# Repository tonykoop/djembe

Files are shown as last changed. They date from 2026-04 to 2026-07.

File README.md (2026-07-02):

# Djembe — Engineering Documentation for a Stave-Built Drum

> *Stave-built djembes — a technique I learned at Morgan Drums (St. Paul, MN) in March 2010 and have been refining as both a craft and an engineering problem ever since.*

Hero photo

## What this is

Engineering documentation for the stave-built djembe — a drum that is traditionally **carved from a single piece of hardwood** but that I've been building from **stave construction** for 16+ years. This repository combines three threads:

1. **Acoustics research** I conducted in college on how djembe geometry produces its characteristic tone.
2. **CAD geometry** for the goblet-profile body and the curved stave shapes that approximate it.
3. **Jig design** for the cutting fixtures that make stave-built djembes reproducible — the new engineering contribution this repo is built around.

Sister project (and methodological ancestor) of [`ashiko-drum-workshop`](https://github.com/tonykoop/ashiko-drum-workshop).

**Status:** L2 V5 build-packet candidate

## Readiness

L2 scaffold — previously a bare-bones readiness packet; this pass fills in
the missing V5 surface (README status line, `CAD/mcp-session-log.md`
provenance, `visual-output-register.csv` rows for the new CAD/Wolfram
artifacts, and `evolution/` Stage 0 intake) without upgrading any acoustic or
fabrication claim. Fabrication authority: **not build-ready**. The files
below turn the existing README, CAD archive, photos, and Helmholtz/FEM
analysis into a reviewable starter surface without claiming measured strike
validation or cut-ready geometry.

## Packet Contents

- [`design.md`](design.md) — intent, evidence map, open decisions, and promotion gates.
- [`bom.csv`](bom.csv) — starter material/component list with source and measurement status.
- [`validation.csv`](validation.csv) — strike, shell, head, sourcing, and documentation gates.
- [`validation-loop.csv`](validation-loop.csv) — next-build measurement rows that compare predictions, physical strike data, shell geometry, head setup, and iteration decisions.
- [`visual-output-register.csv`](visual-output-register.csv) — visual authority register for photos, scans, figures, and CAD/archive previews.
- [`risks.md`](risks.md) — acoustic, fabrication, safety, scope, and evidence risks.
- [`photo-shotlist.md`](photo-shotlist.md) — public-safe documentation and validation shots.
- [`capstone-manifest.json`](capstone-manifest.json) — machine-readable packet status and release gates.
- [`explorer.html`](explorer.html) — generated studio index for reviewing the starter packet and existing evidence.
- [`CAD/djembe.scad`](CAD/djembe.scad) — parametric OpenSCAD goblet-body envelope master (S/M/L Morgan profiles from `CAD/djembe-body/parametric-goblet.csv`); authority `pending_measurement`.
- [`wolfram/djembe-goblet-acoustics.wl`](wolfram/djembe-goblet-acoustics.wl) — lumped-Helmholtz cavity acoustics source model for the same S/M/L profiles; source-only, authority `derived_preview`.
- [`CAD/mcp-session-log.md`](CAD/mcp-session-log.md) — V5 provenance log for CAD-authoring, Wolfram, and packet-refresh sessions.
- `evolution/` — evolution-pipeline Stage 0 intake: master manifest, design-intent, and revision register (Gate A not yet run).

The existing analysis in [`analysis/helmholtz-fem/`](analysis/helmholtz-fem/)
is analysis evidence only. Empirical mic/FFT strike measurements, reviewed
CAD/DXF/design-table geometry, and shop safety checks are still required before
this repo should be treated as a build-ready djembe packet.

The V5 promotion path for issue
[#4](https://github.com/tonykoop/djembe/issues/4) is therefore conservative:
the repo now has an explorer, manifest, validation loop, visual authority
register, a parametric OpenSCAD goblet-body envelope master, and V5
provenance/evolution intake, but shell wall thickness, head setup,
rim/tensioning hardware, and strike measurements remain explicit blockers
before any family or shop-packet claim.

## Background

The djembe is a goblet-shaped hand drum originating with the **Mande peoples of West Africa** — Mali, Guinea, Burkina Faso, Côte d'Ivoire, Senegal. Traditionally it is carved from a single piece of West African hardwood (lenge, djalla, dugura) with a goatskin head and rope tuning. Its sound profile is unusually wide for a hand drum: a deep bass tone from the open center, a sharp open tone from the rim, and a high slap tone played with the fingertips on the rim.

I started building drums professionally at **Morgan Drums**, a small family company in St. Paul, Minnesota, in **March 2010**. That early tenure is signed and dated inside one of the Morgan Drums djembes I worked on there:

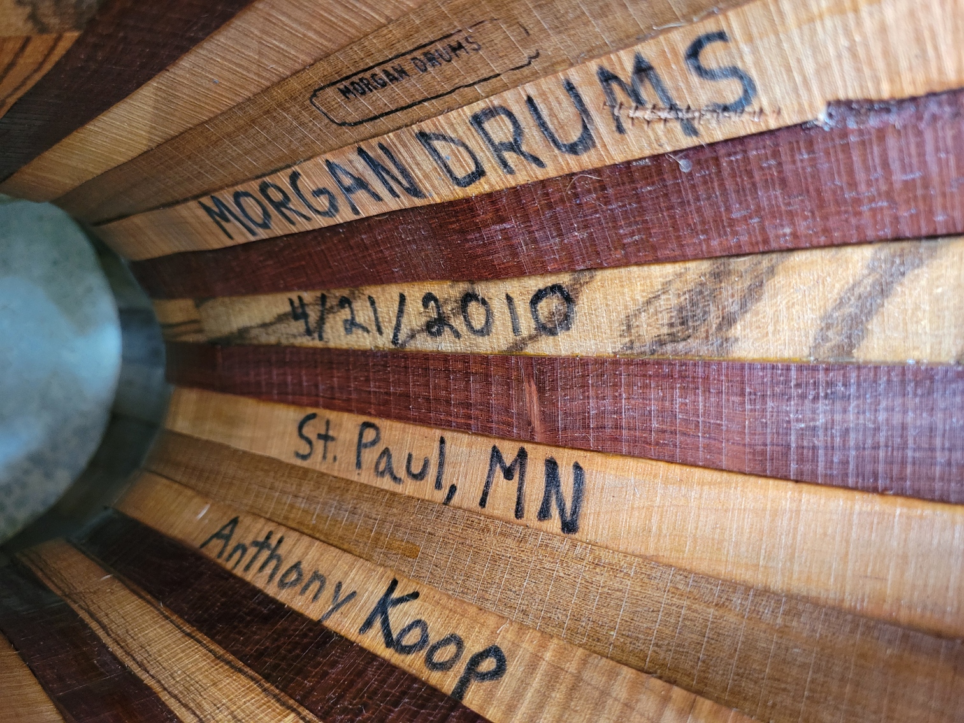
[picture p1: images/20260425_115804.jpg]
Signature inside a stave-built djembe — Morgan Drums, St. Paul MN, 4/21/2010

*Signed inside the shell on **April 21, 2010** during my early Morgan Drums period. This one is a good provenance photo because it reflects work I did on the drum without implying I cut the original staves myself.*

Morgan Drums introduced me to the design choice this entire repository circles around: **building djembes from staves rather than carving them.** It's not the traditional method, and it's significantly harder to engineer correctly — but it lets you use locally-sourced North American hardwoods, cuts material waste dramatically, and produces a drum with a distinctively bright, articulate tone because the stave seams act as small acoustic discontinuities.

## The engineering challenge

A djembe has a **goblet profile** — a wide bowl at the head, a narrowing neck, and a flared foot. This is the engineering reason most djembes are carved rather than staved.

Compare it to an ashiko, which is essentially a truncated cone with a single constant taper angle. An ashiko stave is a straight, tapered piece of wood, and every stave in a drum has the same compound miter angle. **My ashiko workshop produced 16 drums with that single-angle approach** ([documentation](https://github.com/tonykoop/ashiko-drum-workshop)).

A djembe stave does not have that property. Because the body's diameter changes nonlinearly along its height — large at the bowl, small at the neck, large again at the foot — the **compound miter angle that makes adjacent staves meet flush also changes along the stave's height.** A stave that is correctly cut at the bowl will leave gaps at the neck. A stave that fits at the neck will overlap at the bowl.

There are roughly three ways around this problem:

- **Approach A — Segmented stack.** Build the drum as a stack of short staved "rings," each ring with its own constant compound angle. Glue the rings together vertically. This is essentially how segmented woodturning is done. It works, but the horizontal seams are visible and acoustically distinct.
- **Approach B — Curved staves.** Cut each stave as a *curved* piece from a thicker hardwood blank, so the stave's edge profile follows the body curve. This is geometrically what you want, but it's expensive in material and requires a cutting fixture that can produce a smooth curved profile reproducibly. This is the approach I built with at Morgan Drums.
- **Approach C — Rough-cut and lathe-finish.** Stave-build a slightly oversized cylindrical or conical body, then lathe-turn the goblet profile into the outside surface. The stave seams are interior structural elements and the visible exterior is turned. 

The jig design work in this repository targets **approaches B and C** — the geometry is shared, and a fixture that can produce a curved-edge stave is the same kind of thing as a fixture that can guide a lathe gouge through a goblet profile.

Hand-drafted segmented djembe — 27-ring stack approximating the goblet profile, with per-ring dimensional table
*Approach A worked out by hand: a **27-ring segmented-stack design** for a 10"×20" djembe, dated 9/8/2020. The two mirror-image profiles show the goblet outline approximated by a stack of horizontal rings — wide at the head (rings 1–8 ≈ 10.5" OD), narrowing through the neck (rings 13–22 ≈ 5–5.5" OD), then flaring back to the foot (rings 24–27 climbing back to ~8" OD). The right-hand column tabulates the per-ring spec — height (column A), thickness (column B), and outer diameter — so each ring becomes a constant-angle stave problem (the ashiko geometry, just at a different diameter for every ring) instead of a variable-angle one. The visible smooth-curve overlay on top of the stepped profile is the target goblet silhouette this stack approximates; the stair-step error is the inherent cost of Approach A and the reason Approaches B and C exist. **This drawing is the geometry behind the bullet point above** — proof that the segmented approach was worked out as a real design alternative before the jig design effort settled on the curved-stave / lathe-finish path.*

That segmented path is no longer just a note in the README: the recovered archive in [`CAD/Segmented Djembe/`](CAD/Segmented%20Djembe/) now focuses on the djembe-specific branch of that work, with large and small segmented djembe variants, rendered previews, and summary exports. The ashiko and conga-related files that were originally mixed into this folder have now been split back out into their sister repositories so each instrument keeps its own design history.

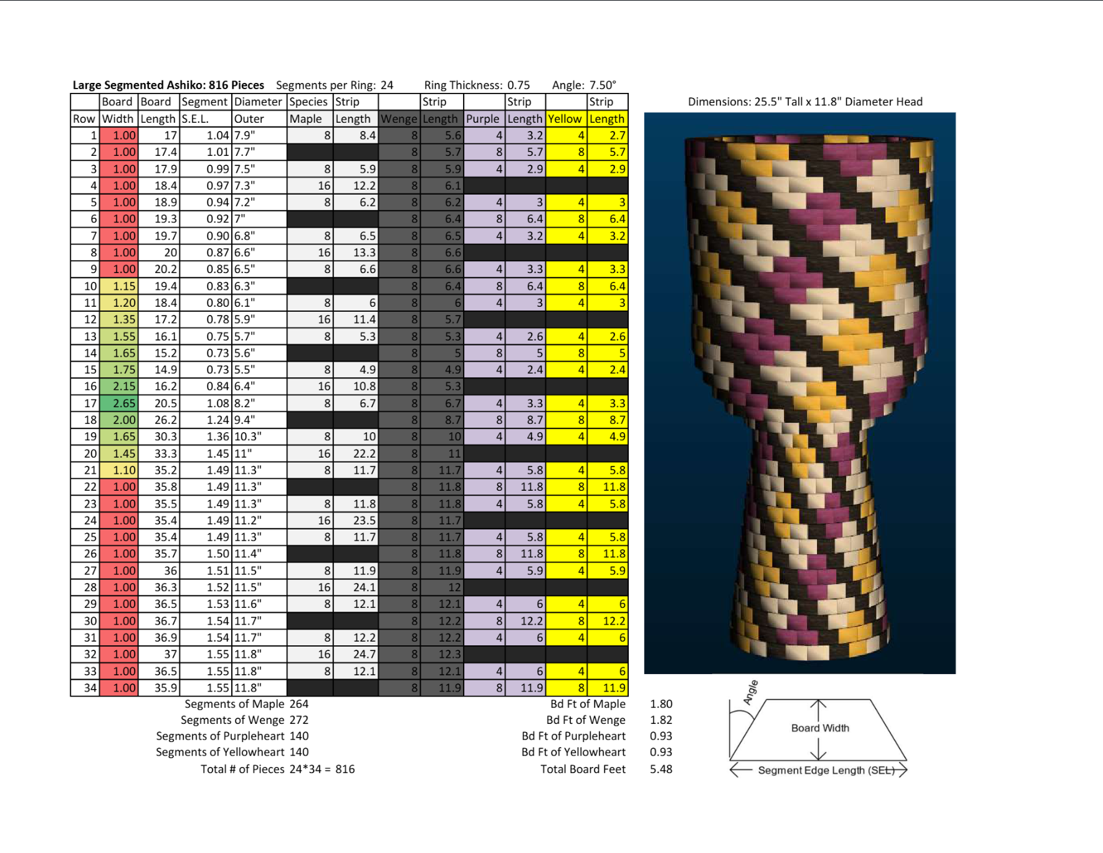
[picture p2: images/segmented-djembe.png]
Segmented djembe planning sheet and concept render

*A later segmented-study sheet: ring-by-ring dimensions and wood-species planning at left, concept rendering at right. Even though the segmented build path was not the final direction I settled on for stave-built djembes, this image shows the design problem being worked through seriously as a manufacturable alternative.*

## Acoustics research — bass-tone analysis (undergrad presentation)

In undergrad I presented an acoustics study modeling the djembe **bass tone** as a **Helmholtz resonator** — the air cavity inside the bowl, coupled to the open drumhead aperture, behaves like a spring-mass system whose resonant frequency sets the deep, low tone you hear when you strike the center of the head.

The fundamental result is the Helmholtz frequency:

$$f_H = \frac{v}{2\pi}\sqrt{\frac{A}{V_0 \cdot L_e}}$$

where *v* is the speed of sound (~13,500 in/s), *A* is the port (drumhead) area, *V₀* is the cavity volume, and *Lₑ* is the effective port length. For a djembe builder, the engineering question reduces to: **what does V₀ need to be to land on a target bass frequency?**

For this study I use a room-temperature air value for *v* because the djembe problem is a struck-membrane / room-air cavity problem. The [`didgeridoo`](https://github.com/tonykoop/didgeridoo) repo uses a warmer breath-temperature speed of sound intentionally, because it models a player-driven air column.

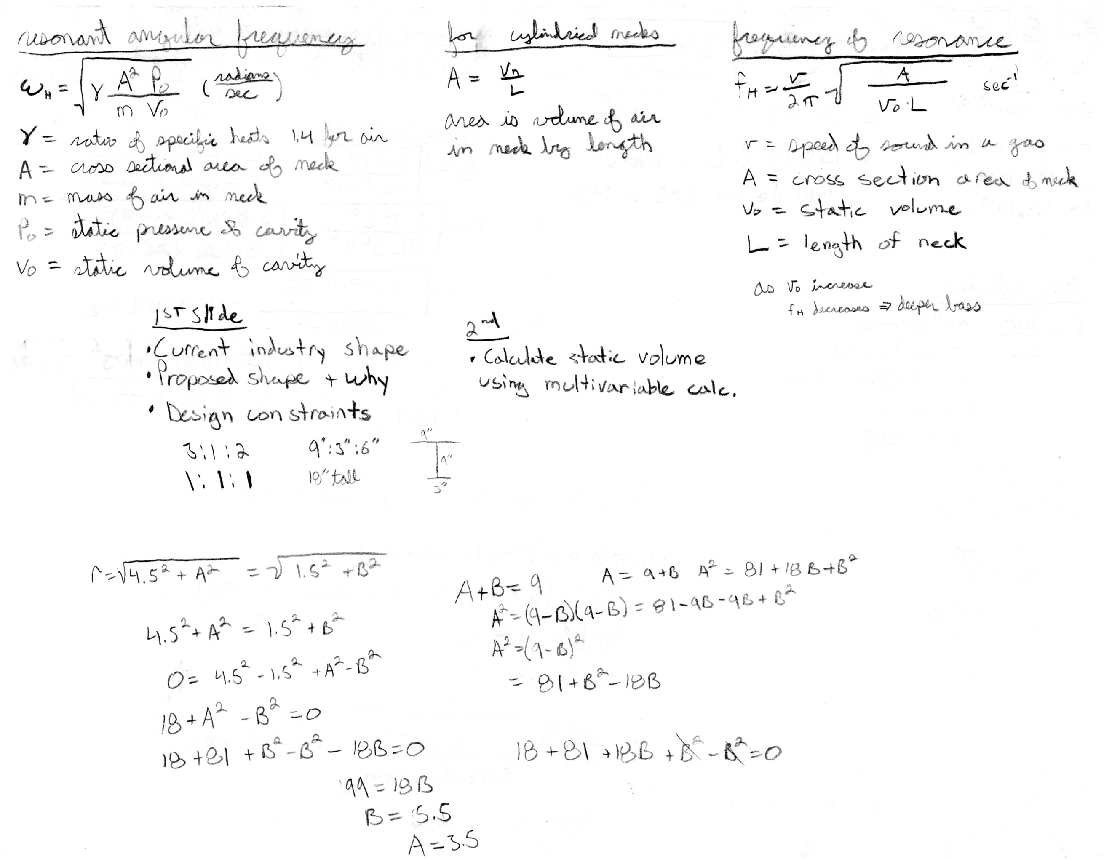
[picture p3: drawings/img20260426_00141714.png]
Helmholtz formula derivation, slide outline, and the deeper-bass design rule

*The presentation outline (top-center): "1st slide: current industry shape · proposed shape & why · design constraints (3:1:2 = 9":3":6", 1:1:1, 10" tall) — 2nd: calculate static volume using multivariable calc." Top-left and top-right: the resonant-frequency formulas, derived in both angular form (`ωH = √(γAP₀/(mV₀))`) and the practical Helmholtz form. The annotation that ties the whole study together is in my own writing under the "frequency of resonance" block: **as V₀ increases, fH decreases ⇒ deeper bass.** That single sentence is the design rule the entire study supports — bigger bowl, lower bass.*

### The geometry problem behind the volume

Most of the eleven pages of working aren't acoustics — they're **geometry**. To get *V₀* for a real djembe profile, I had to:

1. Fit a circular arc through three measured points on the bowl's silhouette (head opening, widest point, neck).
2. Take that arc's surface of revolution about the drum axis.
3. Integrate over the bounded section to get the enclosed cavity volume.

The disk method gave me a closed form:

$$V_0 = \pi (b - a) \left[ R^2 - \tfrac{1}{3}(b^2 + ab + a^2) \right]$$

— and from there it was a matter of running numbers for the geometry I wanted.

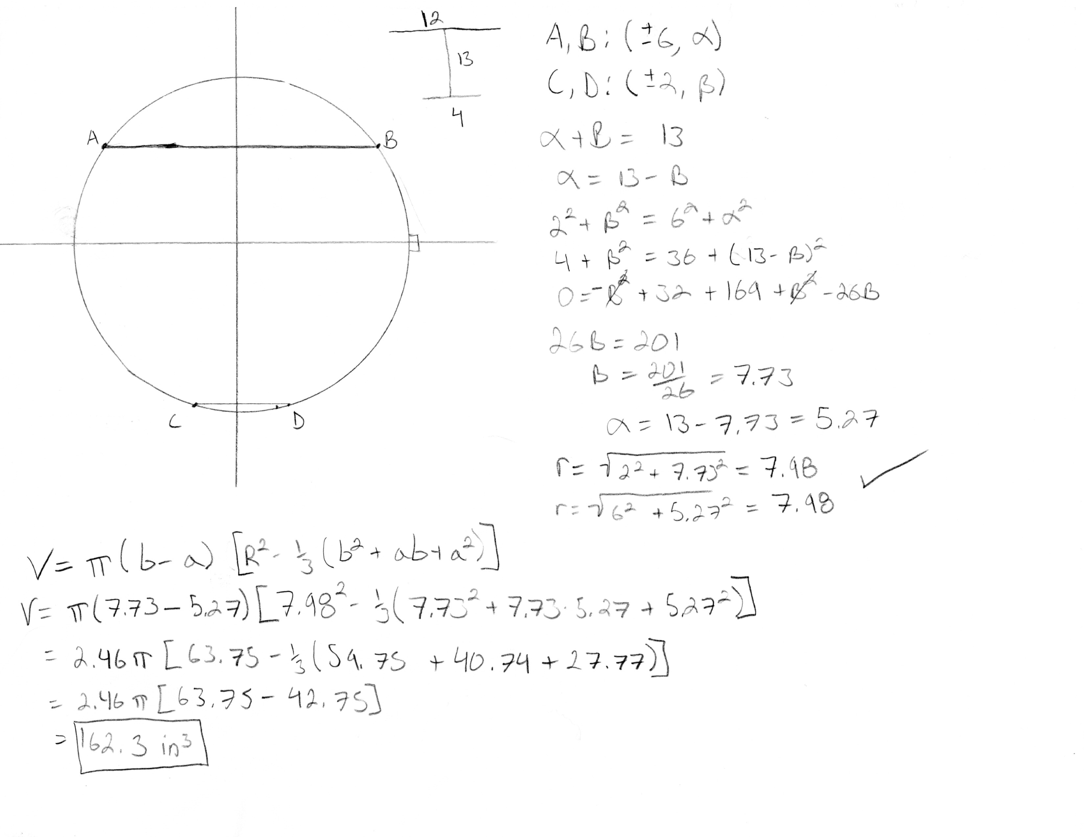
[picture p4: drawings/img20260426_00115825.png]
Single-page derivation: circle-through-three-points algebra, then disk-method volume integral evaluated to V₀ = 162.3 in³

*A clean single-page worked example. Top-left: three points (A,B at ±6, C,D at ±2) and the constraint that they all lie on a circle of unknown radius — the algebra in the top-right column solves the simultaneous equations, gives R = 7.98. Bottom: the volume integral evaluated symbolically and numerically to **V₀ = 162.3 in³** for that geometry.*

### Sweeping the design space

The fun part of having the model is that you can ask "what if?". I ran the calculation for both industry-standard and proposed shapes, and for variants in overall drum height. Small changes in profile produce predictable shifts in bass tone — exactly the design lever a builder wants:

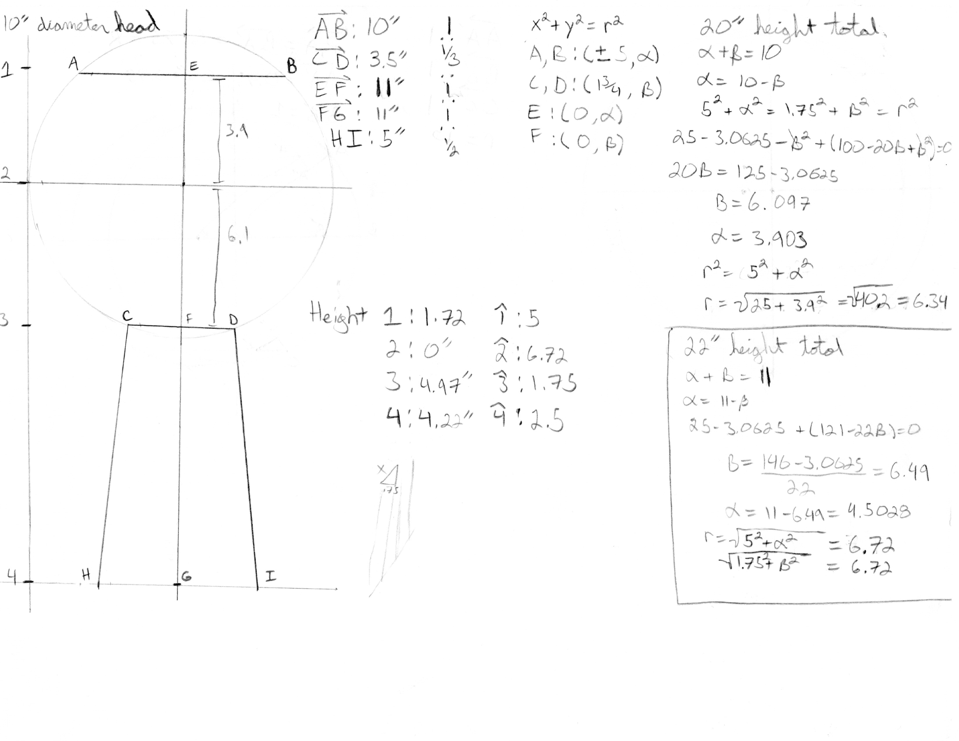
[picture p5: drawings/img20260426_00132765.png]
Two drum-height variants compared with full point-coordinate setup, showing R = 6.34 vs R = 6.72

*A two-case sweep: 20"-tall total → R = 6.34, and 22"-tall total → R = 6.72, with full point-coordinate setup at right (head, midpoint, neck and foot points). Sweeping overall height like this lets you trade off bass depth against ergonomics and material cost. The mini-elevation drawing on the left shows the actual djembe profile being measured.*

Across the geometries I computed, the predicted bass fundamental *fH* landed in the **~100–140 Hz** range, which sanity-checks against measured djembe bass tones (typically 80–120 Hz).

### Scope and what's next

This study modeled the **bass tone only** — the deep tone produced by air-cavity Helmholtz resonance. The **open** and **slap** tones a djembe player produces with rim strikes are governed by very different physics: **circular-membrane Bessel modes** on the goatskin head, set by head tension and head diameter, not by cavity volume. Those weren't part of this undergrad presentation; modeling them would be a separate study.

All eleven pages of the original handwritten working — including the false starts, an *"I isn't diameter! only part of top"* mid-derivation correction in the sphere-resonance section, and the comparison against [drums.org](https://drums.org)'s published Mande proportions — live in [`drawings/`](drawings/).

The study informs the geometry choices in `/CAD/djembe-body/` — particularly the bowl-volume target the jig designs will need to hit for a chosen bass tone.

### L3-frontier follow-up: full-cavity FEM

The lumped Helmholtz model treats the bowl above the neck as one cavity coupled through a zero-volume port. The goblet's foot section is dropped from the formula entirely — and the [`analysis/helmholtz-fem/`](analysis/helmholtz-fem/) study published alongside this README quantifies how much that omission costs. A pure-numpy 1D Webster's-horn FEM (verified against analytic uniform-tube modes to 0.5%) on the parametric goblet profile gives a fundamental that is **25–38% lower** than the lumped prediction across the three Morgan Drums sizes — well above the ~20% "the goblet effect is real" threshold from issue [#1](https://github.com/tonykoop/djembe/issues/1). See [`analysis/helmholtz-fem/results.md`](analysis/helmholtz-fem/results.md) and the deck at [`analysis/helmholtz-fem/capstone.md`](analysis/helmholtz-fem/capstone.md). Empirical (mic + FFT) validation is the L4 follow-on — explicitly deferred at this stage.

## CAD and jig design

> *(Forthcoming — actively in progress.)*

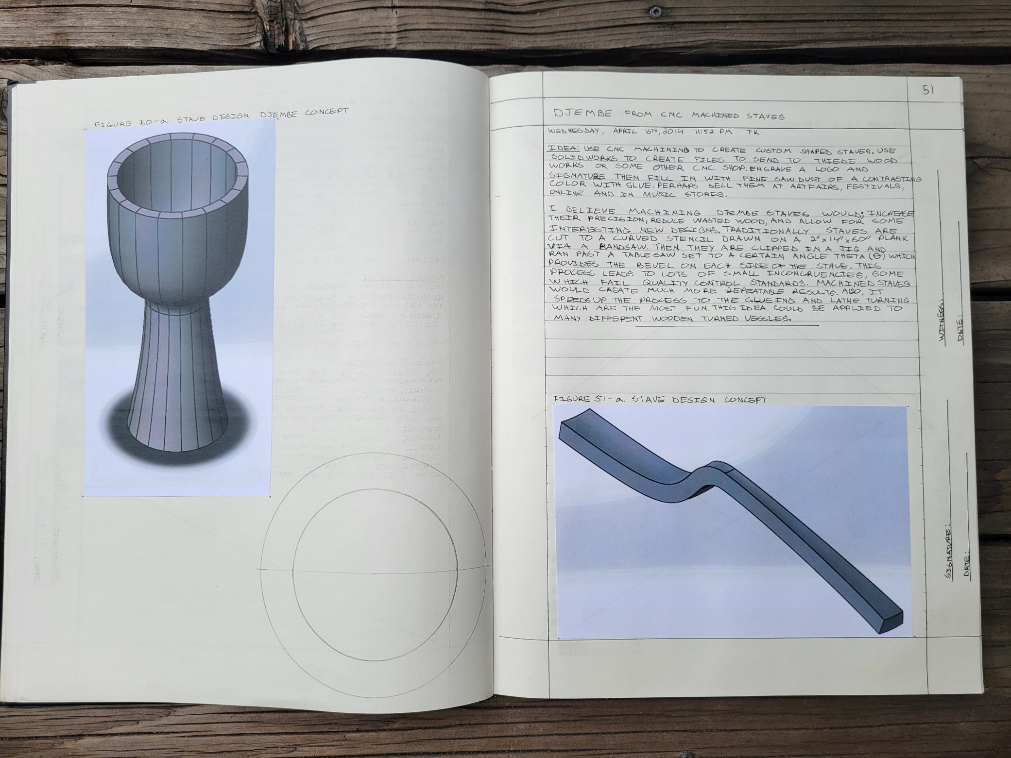
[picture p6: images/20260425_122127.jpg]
2014 engineering notebook entry — "Djembe from CNC machined staves"

*Page 51, Wednesday April 16, 2014: the original notebook entry where the CNC-machined-stave concept was sketched. Figure 60-a shows the full goblet-body concept; Figure 51-a shows a single-stave concept geometry. The text outlines the idea of using CNC to cut custom-shaped staves, fill seams with contrast sawdust + glue, and sell at art fairs and music stores — the seed of the jig design work this repo is built around.*

Repository structure is laid out for:

- `/CAD/djembe-body/` — the target goblet profile, both the Morgan Drums standard sizes (small, medium, large) and any new variants.
- `/CAD/stave/` — stave geometry derived from the target body, by approach (A: segmented rings, B: curved staves, C: rough cylindrical-pre-turning).
- `/CAD/jigs/` — the cutting fixtures. The two key ones I'm working toward:
  - **A curve-profile router jig** that can cut the inner and outer edge curve of a curved djembe stave reproducibly from a thicker blank.
  - **A variable-angle compound miter sled** for the table saw, where the angle indexes against position along the stave so the compound miter changes along the cut rather than staying constant.

One historical archive is already present:

- `/CAD/Segmented Djembe/large-djembe/` — large segmented djembe pattern studies, spreadsheets, and exports
- `/CAD/Segmented Djembe/small-djembe/` — small segmented djembe pattern studies and previews
- `/CAD/Segmented Djembe/misc/` — summary and supporting archive material retained with the djembe branch

Both will be CAD-modeled, drawing-exported, and (eventually) physically built and tested against a small batch of djembes.

## Build history

Two djembes from my Morgan Drums tenure are pictured at the bottom of the hero photo. Both are stave-built, finished with progressive lacquer coats, rope-tuned with 3/16" double-braided polyester, and headed with locally-sourced goatskin. Both are signed and dated inside the bowl.

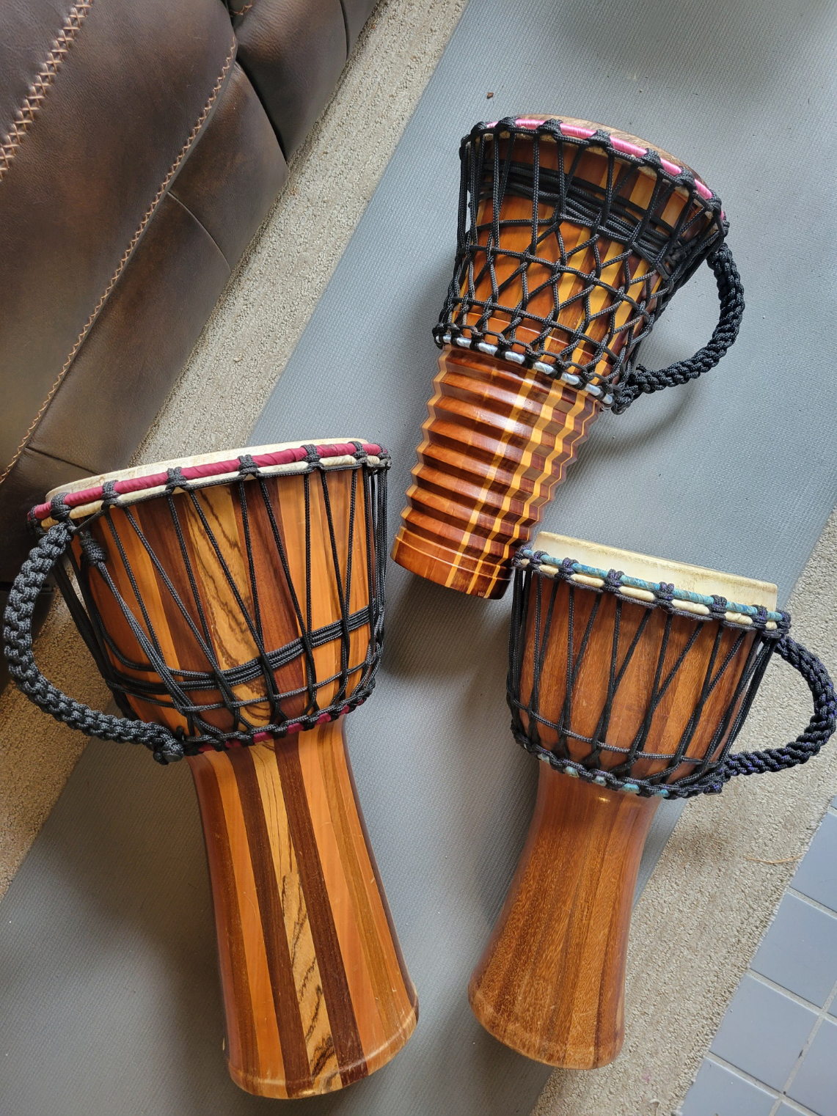
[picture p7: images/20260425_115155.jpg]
Three finished stave-built djembes

*Three of my stave-built djembes side-by-side — different stave-wood combinations, each goblet body lathe-turned, rope-tuned with 3/16" double-braided polyester, and headed with locally-sourced goatskin. The visible vertical seams are the stave joints — a signature of stave construction versus carved-from-solid.*

Build photos from 2008–2013 may exist in personal archives but are not yet recovered. The current photo set in `/images/` documents the finished drums.

## What this work is for

Three audiences:

- **The acoustics question** is for me, and for anyone curious about how djembe geometry sets its tone. The college research nailed down the bass tone via Helmholtz cavity resonance; the open follow-on questions — membrane modes for the open and slap tones, and whether staved versus carved shells differ acoustically at all — are the next steps.
- **The jig designs** are for any drum builder who wants to replicate stave-built djembes without the carved-from-solid-hardwood material cost. The jigs lower the barrier from "Morgan Drums apprenticeship" to "weekend project."
- **The portfolio frame** — for engineers and recruiters reading my GitHub: this repository documents a 17-year continuing craft practice that informs how I think about manufacturing, fixturing, and design-for-reproducibility in my engineering work today. The ashiko workshop ([sister repo](https://github.com/tonykoop/ashiko-drum-workshop)) is the same skill-set applied to a process I scaled to eight other people.

## License

Released under [CC-BY 4.0](LICENSE) — use freely with attribution. The djembe design itself draws on traditional Mande craft; the stave-construction methodology, CAD, jig designs, and analysis in this repository are my own work, free to reuse and adapt with credit.

## Repository structure

```
djembe/
├── README.md                  ← you are here
├── LICENSE                    ← CC-BY 4.0
├── .gitignore
├── research/                  ← college acoustics study + references (forthcoming)
├── analysis/                  ← derived geometry + tone calculations (forthcoming)
├── CAD/
│   ├── djembe-body/           ← target goblet profiles
│   ├── Segmented Djembe/      ← recovered segmented djembe archive
│   │   ├── large-djembe/      ← large segmented variants
│   │   ├── small-djembe/      ← small segmented variants
│   │   └── misc/              ← summary and supporting files
│   ├── stave/                 ← stave geometry, approaches A / B / C
│   └── jigs/                  ← curve-profile router jig + variable-angle sled
├── drawings/                  ← PDF exports of the jigs and key parts
├── images/                    ← drum portraits, signature shots, build photos
└── reference/                 ← any reference documents
```

## Status — current and forthcoming

| Section | Status |
|---|---|
| Repo description, license, gitignore | ✓ done |
| Hero photos | ✓ in progress (Tony photographing now) |
| College acoustics study (bass-tone Helmholtz analysis) | ✓ scanned in — 11 pages in `drawings/`, summarized in README |
| CAD — historical segmented design archive | ✓ recovered and organized in `CAD/Segmented Djembe/` |
| CAD — djembe body geometry | ✓ parametric OpenSCAD goblet-body envelope master (`CAD/djembe.scad`); authority `pending_measurement`, not yet reviewed against a measured template |
| CAD — stave geometry | forthcoming |
| CAD — jig designs | not started |
| Build photos from 2008–2013 | low probability of recovery |

Living document — the historical build context, acoustics derivation, and segmented-archive branch are already in place; the main remaining work is CAD body/stave/jig publication.

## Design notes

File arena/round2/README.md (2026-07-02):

# Arena winner: stave-djembe (round2)

**Generated model** — the winning Code-CAD Arena candidate for this
instrument (entrant `codex-gpt-5.5`, blind-vote wins 3.0, objective pass-rate 0.916667).

This is an AI-generated arena artifact, NOT a measured master or a
validated build packet. See `provenance.json` for the full trial
record. Exported by `makerbench arena export-winners`.

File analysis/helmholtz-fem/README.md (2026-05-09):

# Helmholtz Cavity FEM — Goblet Validation

L3-frontier acoustic-cavity analysis closing the open question in
[`tonykoop/djembe#1`](https://github.com/tonykoop/djembe/issues/1):
does the lumped Helmholtz prediction for a stave-built djembe match a
full wave-equation cavity FEM, and if not by how much?

## Readiness

This analysis is **L3-frontier** per the hardware-development gate:

- ✅ **Physics gate.** Webster's horn equation derived; lumped
  Helmholtz formula documented; assumptions and failure modes called
  out per `skills/helmholtz-cavity-resonator.md`.
- ✅ **Artifact gate.** `parametric-goblet.csv`, three figure plots,
  one machine-readable `results.csv`, one human-readable `results.md`.
- ✅ **Solver-verification gate.** `webster_horn.py` self-checks against
  analytic closed-open uniform-tube modes (within 0.5% at 800 elements,
  used 1200 in production). The check raises on failure; passing it is
  a precondition for the comparison numbers being trustworthy.
- ⏸ **Empirical gate (deferred).** No physical drum was measured.
  The skill doc cites a measured 80–120 Hz range from prior builds; the
  FEM mode-1 numbers (123–190 Hz across S/M/L) are within 1.0–1.5× of
  that range, but this analysis does not claim L4-empirical
  validation. Mic + FFT measurement on the existing stave-built djembes
  is a follow-on.
- 🚫 **Manufacturing / safety gates.** N/A — analysis-only.

## Files

| File | Role |
|---|---|
| [`closed-form.md`](closed-form.md) | A, L_eff, V₀ mapping for the goblet; the lumped baseline |
| [`profile.py`](profile.py) | Parametric `r(z)` profile for S/M/L. Single source of truth for goblet geometry. |
| [`webster_horn.py`](webster_horn.py) | Pure-numpy linear-FE solver for the 1D Webster's horn equation. Self-verifies against analytic uniform-tube modes. |
| [`write_design_table.py`](write_design_table.py) | Emits `CAD/djembe-body/parametric-goblet.csv` from `profile.py`. |
| [`run_comparison.py`](run_comparison.py) | End-to-end driver: solver runs + figures + `results.csv` + `results.md`. |
| [`results.csv`](results.csv) | Machine-readable comparison table (one row per size). |
| [`results.md`](results.md) | Human-readable comparison memo. |
| [`capstone.md`](capstone.md) | Capstone deck (markdown). One slide per heading. |
| [`figures/`](figures/) | `goblet-profiles.png`, `mode-shapes-{S,M,L}.png`, `lumped-vs-fem-bar.png`. |

## Reproduce

```bash
cd analysis/helmholtz-fem

# 1. Sanity-check goblet geometry
python3 profile.py
#   prints V_0 / V_total / A_neck / L_eff / lumped f_H per size

# 2. Verify FEM solver against analytic uniform-tube modes,
#    then run all three goblets
python3 webster_horn.py
#   prints "OK — first 5 modes within 0.5% of (2n-1) c / (4 H)."
#   then prints lowest 3 modes per size

# 3. Generate figures + results.csv + results.md
python3 run_comparison.py

# 4. Re-emit the SolidWorks-style design table CSV
python3 write_design_table.py
```

Pure numpy + matplotlib. No SciPy, FEniCS, gmsh, COMSOL, or external
mesh tooling required. The solver is small enough (1200-element 1D
mesh) to run on any laptop in well under a second.

## Headline result

| Size | Lumped f_H (Hz) | FEM f₁ (Hz) | Δ vs lumped |
|---|---|---|---|
| Small (Morgan-9)  | 299 | 190 | **−36.4%** |
| Medium (Morgan-10) | 270 | 168 | **−37.8%** |
| Large (Morgan-12)  | 165 | 123 | **−25.7%** |

All three deviations exceed the 20% threshold the issue used as the
test for "the goblet effect is real and quantifiable." See
[`results.md`](results.md) for the full table including modes 2 and 3.

## Cross-references

- Issue: [`tonykoop/djembe#1`](https://github.com/tonykoop/djembe/issues/1)
- Skill (canonical formula and provenance):
  [`skills/helmholtz-cavity-resonator.md`](../../skills/helmholtz-cavity-resonator.md)
- Original derivation scan: `drawings/img20260426_00141714.png`
- Worked-example scan: `drawings/img20260426_00115825.png`
- Sister-repo reuse: `tongue-drum/study/README.md` Q4 (cavity coupling),
  `dundun` cavity work

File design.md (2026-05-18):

# Djembe Bare-Bones Design Packet

Current status: bare-bones readiness packet.
Fabrication authority: not build-ready.
CAD/DXF status: future authority unless a reviewed drawing or design table is promoted.
Measurement status: measurement-required for tuning, shell fit, head tension, and jig geometry.

## Intent

This packet organizes the existing djembe repo evidence into a small reviewable
starter packet for a stave-built goblet drum. It does not replace the README,
the historical build notes, the segmented archive, or the Helmholtz/FEM
analysis. It gives the next builder a concrete set of decisions, materials,
and validation gates before the repo can become a shop packet.

The target instrument family is a stave-built djembe: a goblet-shaped hand drum
with a membrane head, open foot, rope tensioning, and a shell profile that
strongly affects the bass cavity mode. The repo currently has historical
finished-drum photos, scanned notebook pages, segmented construction studies,
legacy SolidWorks files, a parametric goblet CSV, and a 1D Webster horn FEM
analysis.

## Evidence Already In The Repo

| Evidence | Current authority | Notes |
| --- | --- | --- |
| `README.md` | narrative and provenance | Strong project story, cultural note, acoustics summary, and current repo map. |
| `analysis/helmholtz-fem/` | analysis scaffold | Solver self-checks against a uniform tube; no physical drum mic/FFT validation yet. |
| `analysis/helmholtz-fem/results.csv` | computed analysis output | Shows FEM mode 1 below lumped Helmholtz predictions for S/M/L profiles. |
| `CAD/djembe-body/parametric-goblet.csv` | parametric geometry reference | Useful for analysis and future CAD, but not a reviewed fabrication drawing. |
| `CAD/Segmented Djembe/` | historical segmented archive | Pattern spreadsheets and previews exist; current manufacturing authority is not established. |
| `CAD/legacy-archive-2018/` | legacy CAD archive | SolidWorks source exists, but review/export status is unknown. |
| `images/` and `drawings/` | documentation evidence | Photos and scans document history and concepts; they are not dimensional authority by themselves. |
| `validation-loop.csv` | next-build validation scaffold | Rows name the prediction, measurement method, status, and next action for strike, shell, head, and construction-path checks. |
| `visual-output-register.csv` | visual authority guard | Photos, scans, figures, and CAD/archive previews are recorded as reference-only until reviewed geometry authority exists. |

## Acoustic Model Boundary

The current bass-tone model treats the djembe cavity as a goblet resonator. The
README and `analysis/helmholtz-fem/results.md` document a useful analysis
result: a full-goblet Webster FEM predicts lower first cavity modes than the
lumped Helmholtz estimate for the S/M/L profiles.

That result is analysis evidence, not empirical validation. Before claiming
validated tuning behavior, the repo needs recorded strike data from real drums:
mic placement, head diameter, head material, tuning state, room conditions,
strike type, FFT method, and repeated measurements for bass, tone, and slap.

## Strike Validation Plan

Use `validation-loop.csv` as the next-build worksheet. The first empirical pass
should capture one identified physical drum, one head/tensioning state, and
three separate strike families:

| Strike family | What it checks | Required context |
| --- | --- | --- |
| Bass / center strike | Whether the cavity-mode analysis is directionally useful for a real drum. | Drum ID, head diameter, head material, tuning state, mic distance, room notes, sample rate, FFT window, and repeated takes. |
| Open tone | Whether rim/edge membrane response is being confused with the bass cavity model. | Strike position, hand technique, head/tension metadata, and repeated takes. |
| Slap | Whether the high transient content is documented separately from modeled cavity resonance. | Strike position, head/tension metadata, peak/transient notes, and repeated takes. |

Do not revise shell geometry from strike results until the shell dimensions,
head setup, rim/ring hardware, and rope tensioning state are recorded in the
same measurement bundle.

## Design Decisions Still Open

| Decision | Current value | Status | Required evidence |
| --- | --- | --- | --- |
| Construction path | stave-built djembe | assumption | Choose segmented stack, curved staves, or rough-cut plus lathe-finish for the next build. |
| Size target | S/M/L profiles in existing CSV | derived estimate | Confirm physical target dimensions and player ergonomics. |
| Head material and diameter | goatskin / TBD | source needed | Record actual head size, hide source, collar fit, and tensioning method. |
| Rope and ring hardware | rope-tuned / TBD | source needed | Record rope diameter, ring dimensions, knot pattern, and safety factor. |
| Shell wood | North American hardwood / TBD | source needed | Record species, moisture content, blank dimensions, and glue compatibility. |
| Jig geometry | future router jig or miter sled | requires measurement | Promote reviewed CAD/DXF/design table before cutting parts. |
| Acoustic targets | bass cavity mode plus membrane modes | measurement-required | Define target bass, tone, and slap metrics with measured examples. |

## Promotion Gates

This repo can move beyond a bare-bones packet only when:

1. `validation-loop.csv` has measured bass, open-tone, and slap rows for at least one known drum.
2. Shell geometry is captured in a reviewed drawing, design table, or CAD export.
3. Head material, rim/ring hardware, and rope tensioning state are tied to the strike session.
4. BOM and sourcing rows distinguish in-hand parts from supplier-unverified parts.
5. The chosen construction path has a cut list or fixture plan with tolerances.
6. Safety checks cover head tension, rope/ring loads, glue joints, turning work,
   and any CNC/router jig operations.

Until those gates pass, this packet should be read as a scaffold and evidence
map, not as a build-ready djembe plan.

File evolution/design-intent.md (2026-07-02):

# Design Intent — djembe rev A

- Master CAD: `CAD/djembe.scad` (sha256: f54640659c859cbd9a7de8aadafbfd12501861a5ecde3acf5de337ba1b588601), driven by `CAD/djembe-body/parametric-goblet.csv` (sha256: 90f9dbf534af5e27823fdf9080c4d266db8c90001bdd95f90c22255b7c81208c)
- Function: A stave-built goblet-shaped hand drum — wide bowl at the head, narrowing neck, flared foot — with a goatskin (or equivalent) membrane head and rope tuning. The bowl/neck geometry sets the air-cavity Helmholtz bass tone (README.md "Acoustics research"); the open and slap tones are governed separately by membrane modes on the head, not modeled here. Three Morgan Drums size variants (S/M/L) exist in the design table.
- Environment: hand-struck acoustic instrument; rope tensioning is a sustained structural load on the shell and rim hardware; stave joints see glue-line stress during turning and tuning.
- Target qty: 1 (prototype). Deadline: TBD. Budget/unit ceiling: TBD.

## Critical dimensions (carry tolerances)

| Feature | Nominal (medium/M) | Tolerance | Why critical | Source |
| --- | --- | --- | --- | --- |
| Head diameter | 10.0 in | measurement-required | membrane strike area, sets tone/slap character | CAD/djembe-body/parametric-goblet.csv (reference_only) |
| Neck diameter | 5.5 in | measurement-required | Helmholtz neck cross-section area (bass coupling) | CAD/djembe-body/parametric-goblet.csv |
| Foot diameter | 8.5 in | measurement-required | shell stability / floor contact | CAD/djembe-body/parametric-goblet.csv |
| Total height | 20.0 in | measurement-required | overall bowl volume, drives bass frequency target | CAD/djembe-body/parametric-goblet.csv |
| Neck z-window (top/bottom, from head) | 4.66 in / 6.66 in | measurement-required | sets effective neck length L_eff in the Helmholtz model | CAD/djembe-body/parametric-goblet.csv |
| Shell wall thickness | TBD | not yet defined | structural load path + tone; do not thin below a floor once set | bom.csv, cut-list.csv (both TBD) |
| Head tension / rope schedule | TBD | not yet defined | membrane mode tuning, safety (stored energy) | risks.md; validation.csv DJM-VAL-005 |

## Incidental (free for DFM)

- Exterior finish (lacquer/oil), stave wood species selection within sourcing constraints, rope color/pattern, decorative seam treatment.

## Must-nots (DFM may never violate)

- Do not cut/turn shell stock until a construction path (segmented stack / curved staves / rough-cut-and-lathe-finish) is chosen and recorded (risks.md "Fabrication Risks"; validation.csv DJM-VAL-006).
- Do not treat the legacy SolidWorks archive (`CAD/Djembe/`, `CAD/Segmented Djembe/`, `CAD/legacy-archive-2018/`) or the Helmholtz/FEM analysis as fabrication authority — both are analysis/historical reference until strike-validated (risks.md "Scope Risks", "Acoustic Risks").
- Do not exceed rope/ring tension design values without a safety review — rope-tuned shells store energy and can fail during tuning (risks.md "Safety Risks").
- Do not skip scrap/coupon trials for router or lathe jig operations before committing instrument-grade stock (risks.md "Fabrication Risks").
- Do not model bearing edge, head/rim hardware, or jig geometry in `CAD/djembe.scad` — these stay measurement-required per the master's header comment and validation.csv DJM-VAL-005/DJM-VAL-007.

## Material intent

Per `bom.csv` (all rows currently source-needed / measurement-required): TBD North American hardwood shell blank, goatskin (or equivalent) drum head, tuning rope, steel tensioning rings, stave adhesive, and finish. No supplier or price data is verified in this packet — see `sourcing.csv`.

## Stage status

Stage 0 intake complete 2026-07-01. Gate A (Alpha shop compile) NOT yet run — no concessions logged, nothing presented as shippable.

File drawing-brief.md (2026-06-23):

# Drawing Brief — Djembe — Stave-Built Goblet Drum

## Required Drawing Set

- Plan view: outside diameter, inside diameter (if applicable), head seat, and center.
- Cross-section: depth, wall thickness, and bearing-edge radius.
- Shell development / stave layout: miter angle, rough and final dimensions.
- Jig / fixture layout: clamp positions, stop blocks, forming diameter.
- Tensioning / tuning hardware detail: lug spacing, cord path, or rod positions.

## Datum Plan

- **Datum A** — drum center plane (axial reference).
- **Datum B** — bearing edge (front head seat).
- **Datum C** — stave seam or shell seam reference.

## Authority Note

All drawings are **first-prototype estimates** until a physical build validates
shell roundness, head fit, and tension response.  Promote a drawing from
`derived_preview` to `fabrication` authority only after measured dimensions
confirm the predicted geometry within acceptance tolerances.

## View Checklist

- [ ] Plan view (top-down, showing head area)
- [ ] Elevation / side view (full height with bearing edge)
- [ ] Cross-section (wall, bearing-edge radius, any internal profile)
- [ ] Stave / segment layout (if stave-built)
- [ ] Hardware detail (lugs, hooks, rods, or rope path)
- [ ] Jig / fixture drawing (if custom tooling required)

*See `visual-output-register.csv` for the authority status of each drawing file.*

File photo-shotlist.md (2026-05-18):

# Djembe Photo Shotlist

Current status: documentation plan.
Fabrication authority: not build-ready.

Use these shots to document evidence and context. Photos should not be treated
as dimensional authority unless the frame includes a scale reference and the
measurement is also recorded in a table.

| shot_id | subject | purpose | required context | authority |
| --- | --- | --- | --- | --- |
| DJM-PHOTO-001 | Three finished djembes hero | Public overview and portfolio orientation | Instrument names if known and non-private context | documentation |
| DJM-PHOTO-002 | Interior signature/provenance | Build-history evidence | Date, builder role, and what the photo does not prove | provenance |
| DJM-PHOTO-003 | Head close-up | Capture head material, collar, and condition | Scale ruler and head diameter if used for validation | measurement-support |
| DJM-PHOTO-004 | Rope and ring detail | Tension hardware documentation | Rope diameter, ring diameter, knot pattern | measurement-support |
| DJM-PHOTO-005 | Foot and neck profile | Shell geometry context | Scale ruler and target S/M/L profile if applicable | measurement-support |
| DJM-PHOTO-006 | Segmented archive sheet | Document historical construction alternative | File path and whether it is current or historical | documentation |
| DJM-PHOTO-007 | Parametric goblet table screenshot | Connect CAD profile data to analysis | CSV path and generated date if re-emitted | documentation |
| DJM-PHOTO-008 | FEM plot set | Show analysis outputs | Link to `analysis/helmholtz-fem/results.md` | analysis-support |
| DJM-PHOTO-009 | Strike measurement setup | Future acoustic validation | Mic distance, room, strike type, sample rate | validation |
| DJM-PHOTO-010 | Jig or fixture mockup | Future fabrication validation | Workholding, guards, and scrap-test status | validation |
| DJM-PHOTO-011 | Stave blank layout | Future material planning | Species, moisture, blank dimensions | validation |
| DJM-PHOTO-012 | Finished shell inspection | Future build documentation | Glue lines, cracks, roundness, and finish state | validation |

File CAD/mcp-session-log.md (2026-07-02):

# MCP / External-Tool Session Log

V5 provenance record for artifacts generated or modified by external tools.
Required before claiming any artifact came from OpenSCAD, Blender, Illustrator,
Photoshop, Fusion, SketchUp, or similar tooling.

| session_id | tool | input_authority | outputs | role | authority_result | review_status | notes |
|---|---|---|---|---|---|---|---|
| fable-v5-refresh-2026-07-01 | claude-code (Fable 5) + OpenSCAD CLI | CAD/djembe-body/parametric-goblet.csv, design.md | CAD/djembe.scad | cad_authoring | pending_measurement | self_checked | Parametric goblet-body envelope master: head/neck/foot diameters, neck z-window, and total height read verbatim from parametric-goblet.csv (S/M/L Morgan profiles); neck cross-section area recomputed in-file as a design-table self-check (computed=23.7583, csv=23.7583 for medium). Wall thickness/hollow interior NOT modeled (no value in bom.csv/cut-list.csv, both TBD); stave layout, jig geometry, bearing edge, and head/rope hardware are out of scope (see risks.md, drawing-brief.md). OpenSCAD render check: pass (openscad -o STL, exit 0). |
| fable-v5-refresh-2026-07-01 | claude-code (Fable 5) | CAD/djembe-body/parametric-goblet.csv, README.md, analysis/helmholtz-fem/results.csv | wolfram/djembe-goblet-acoustics.wl | analysis_source | derived_preview | unreviewed | Pre-existing lumped-Helmholtz cavity acoustics source model for the Morgan S/M/L profiles; source-only, not executed (wolframscript not run this pass). Row added to visual-output-register.csv and this log for V5 provenance completeness; file content unchanged. |
| fable-v5-refresh-2026-07-01 | claude-code (Fable 5) | design.md, CAD/djembe-body/parametric-goblet.csv | bom.csv, sourcing.csv, cut-list.csv, validation.csv | packet_refresh | fabrication | self_checked | V5 refresh pass: existing tabular packet data reviewed against design.md/parametric-goblet.csv baseline; no dimension changes made, all TBD/measurement-required markers left as-is. Provenance rows added to satisfy V5 fabrication-artifact logging. |

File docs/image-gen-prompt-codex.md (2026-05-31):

# Djembe Image-Gen Prompts

Concept visualization only; not fabrication authority. Do not infer goblet
geometry, jig dimensions, rope loads, head setup, or tuning from these prompts.

## Hero Prompt

Photorealistic 3/4 product photograph of a stave-built djembe with a goblet-shaped hardwood body: wide bowl, narrow neck, flared foot, visible vertical stave seams, lathe-smoothed exterior, natural goatskin head, metal rings, and braided rope tuning. The drum should look like a refined engineering-documentation object, not a mass-market import: locally sourced hardwood tones, signed-maker craft energy, clean rim work, and a bright articulate stave-built character. Clean studio background, soft directional lighting, realistic scale from a hand or beater nearby, 50mm lens, high detail, photorealistic.

## In-Context Prompt

Photorealistic scene of the stave-built djembe in a woodworking and acoustics workspace: one player sits with the drum tilted slightly forward for bass, tone, and slap testing, while nearby are scanned geometry notes, a tuner, rope tensioning tools, and a curved-stave or segmented-ring study on the bench. Natural light, believable hand posture, respect for the instrument's Mande origin without invented decoration.

## Detail / Macro Prompt

Photorealistic macro close-up of the djembe neck and head transition: natural goatskin folded over rings, braided rope tensioning, vertical stave seams curving into the goblet shoulder, and smooth lacquered hardwood grain. Show real knots, ring contact, shell curvature, and handmade surface detail. High-detail macro, shallow depth of field.

## Negative / Avoid

No text, logos, watermarks, impossible rope paths, fake tribal patterns, extra limbs, distorted hands, toy proportions, or cutaway dimensions.

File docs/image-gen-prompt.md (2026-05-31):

# Image-Gen Prompts

Concept image only; not fabrication authority. Do not include cut-ready dimensions, hole locations, or toolpaths.

## Hero Prompt

A single finished stave-built djembe standing upright as a real physical object, shown in a clean three-quarter product-photography angle, ~50mm lens. The drum has the unmistakable goblet silhouette: a wide rounded bowl at the top carrying a taut natural goatskin head, narrowing through a slender waisted neck, then flaring back out to an open foot that the drum rests on. The shell is built from vertical wooden staves rather than carved from one log — subtle vertical glue seams run head-to-foot down the lathe-turned hardwood body, mixing two warm North-American hardwood tones with a smooth progressive lacquer finish that catches the light. The head is held by a metal collar ring and rope-tuned with a mesh of pale double-braided polyester rope laced in the classic vertical-and-diamond Mali weave between a top crown ring and a lower ring, the verticals running taut down the bowl. The goatskin head shows faint natural grain and edge translucency near the rim. Realistic tabletop scale of a knee-height hand drum. Clean neutral seamless studio background, soft directional studio key light with gentle fill, high detail, photorealistic, no text labels.

## In-Context Prompt

The same stave-built goblet djembe staged in a warm woodworking shop or small drum studio, sitting on a plank workbench beside coils of pale tuning rope and a hardwood stave blank, late-afternoon natural window light raking across the lacquered shell to reveal the vertical stave seams and the rope lacing down the bowl. Shallow depth of field with the goblet body sharp and the bench tools softening into bokeh behind it, environmental storytelling of a craft-built drum mid-life in the shop, concept visualization only, photorealistic.

## Detail Prompt

Macro close-up of the djembe's signature rope-tuning system and stave seams: the metal flesh/crown ring seating the folded goatskin head edge, the vertical pull ropes of pale double-braided polyester running taut from the upper ring, and the diamond-knot tuning weave cinching them, with the lathe-turned hardwood bowl and its faint vertical stave glue lines filling the background. Raking side light emphasizes rope braid texture, the natural grain of the goatskin, the lacquer sheen, and the two-tone wood seams. High detail, shallow depth of field, no measurements.

## Negative / Avoid

No text, logos, watermarks, or fake maker marks; no dimension callouts, rulers, or tuning-number labels; no impossible mechanisms or floating rope; goblet proportions stay plausible; anatomically plausible hands if a player is shown.

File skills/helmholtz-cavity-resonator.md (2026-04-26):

---
name: helmholtz-cavity-resonator
domain: acoustics
description: |
  Predict the bass-tone fundamental frequency of a closed cavity coupled to
  one or more open ports (drum body + drumhead aperture, NAF flute slow-air
  chamber + flue, tongue drum interior + sound port, bottle + neck). Uses
  the Helmholtz lumped-element resonator formula plus a port end-correction.
status: validated against measured djembe bass tones (100–140 Hz prediction
  vs 80–120 Hz typical measurement)
canonical-location: tonykoop/djembe/skills/helmholtz-cavity-resonator.md
also-referenced-from:
  - tonykoop/djembe/README.md (Acoustics research section)
  - tonykoop/tongue-drum/study/README.md (cavity-coupling Q4 + bilateral Q7)
  - tonykoop/tongue-drum/SKILLS.md
provenance: |
  First derived from first principles in my undergrad acoustics
  presentation, ca. 2010. Original handwritten derivation scanned 2026-04-26
  into tonykoop/djembe/drawings/img20260426_*.png — particularly
  img20260426_00141714.png (formula + design rule "as V₀ increases, fH
  decreases ⇒ deeper bass") and img20260426_00115825.png (worked example
  computing V₀ = 162.3 in³ via the disk method).
audience: human (engineers, recruiters, drum builders) + agent (CLI / robotic)
maintainer: Tony Koop
license: CC-BY 4.0
---

# Helmholtz Cavity Resonator — Personal Skill

> *Predict the deep bass tone of an instrument or container by treating its enclosed air as a Helmholtz resonator. Reusable across drums, flutes, slit-tongue drums, and any closed-cavity-with-port geometry.*

## When to invoke this skill

You are predicting (or designing for) the fundamental bass tone of a cavity-with-port system:

- **Stave-built drums** — body cavity coupled through the drumhead aperture (djembe, dundun, frame drum, ashiko, conga).
- **Tongue/slit drums** — body cavity coupled through the slit openings.
- **NAF flutes** — slow-air chamber acting as the cavity, the flue as the port (a different acoustic role than the playing chamber).
- **Any rigid-walled hollow body with an opening** — bottles, gourd resonators, ocarinas in a limit, the cavity behind a guitar's sound hole.

**Don't invoke when:**

- The wavelength of interest is comparable to or smaller than the cavity dimensions (the lumped approximation breaks; you need the full wave equation).
- The port is so large there's no real constriction (e.g. a goblet glass).
- You care about higher modes — this gives only the fundamental.
- The cavity wall is itself a strong resonator (e.g. a tightly-tuned drumhead) — then you have a coupled-oscillator system and need a coupled model, not Helmholtz alone.

## The formula

$$f_H = \frac{c}{2\pi}\sqrt{\frac{A}{V_0 \cdot L_{\text{eff}}}}$$

Where:

| Symbol | Meaning | Typical units |
|---|---|---|
| *c* | Speed of sound in air | ~13,500 in/s, ~343 m/s at 20 °C |
| *A* | Cross-sectional area of the port | in², m² |
| *V₀* | Static cavity volume | in³, m³ |
| *L_eff* | Effective port length (actual + end correction) | in, m |

**End correction** (essential for short ports — the air mass extends slightly beyond the geometric port ends):

- Flanged opening (port flush with a wall, like most drumhead apertures): add `0.85 · r` per open end
- Unflanged opening (port like a tube into open air): add `0.61 · r` per open end
- Both ends open: add the end correction at both ends

Example: a 1" radius port that's 0.5" long, flanged at one end into the cavity and unflanged at the other (a typical sound port), has L_eff ≈ 0.5 + 0.85 · 1 + 0.61 · 1 = **1.96 in**. Without the end corrections you'd compute fH using L = 0.5 — about 2× too high.

## Method — design loop

1. **Pick the target tone.** What bass fundamental do you want, in Hz? (Convert from musical note via `f = 440 · 2^((n − 49)/12)` where *n* is the piano key number — A4 = 49.)
2. **Compute V₀ for your cavity.**
   - For a simple shape (cylinder, sphere, box), use the closed-form volume.
   - For a non-trivial axisymmetric profile (drum bowl, gourd), fit a circular arc through three measured profile points, then integrate the surface of revolution by the disk method:
     $$V_0 = \pi (b - a)\left[R^2 - \tfrac{1}{3}(b^2 + ab + a^2)\right]$$
     This is the [`circle-through-three-points`](circle-through-three-points.md) + [`surface-of-revolution-volume`](surface-of-revolution-volume.md) companion-skill pair (both stub'd for now; documented in djembe/drawings/ until extracted).
3. **Measure A, L_actual, and the port-end conditions.** Apply end corrections to get L_eff.
4. **Plug into the Helmholtz formula.** Compare predicted fH to target.
5. **Adjust geometry.** Tuning levers, in order of magnitude:
   - **V₀** — *fH ∝ 1/√V₀*. Doubling cavity volume drops fH by ~30%. The dominant lever for bass depth.
   - **L_eff** — *fH ∝ 1/√L_eff*. Lengthening the port (e.g. adding a tube, deepening the wall) drops fH.
   - **A** — *fH ∝ √A*. Smaller port → lower fH, but the square root means the effect is modest for small geometry changes. Easiest to vary if V₀ is fixed.

## Worked examples in my repos

### Djembe ([tonykoop/djembe](https://github.com/tonykoop/djembe))

The original derivation was for djembe bowl + drumhead. Cavity volumes computed from undergrad geometry: 162 in³ (small), 226 in³ (medium), 700 in³ (large). Predicted fH range **100–140 Hz**, sanity-checked against measured djembe bass tones (typically 80–120 Hz).

Full handwritten derivation lives at `djembe/drawings/img20260426_00141714.png` (formula + slide outline + the design rule **"as V₀ increases, fH decreases ⇒ deeper bass"**).

### Tongue drum ([tonykoop/tongue-drum](https://github.com/tonykoop/tongue-drum))

Phase 2 of the planned key-tuning DoE applies this skill to a bilateral-tongue cavity — does damping the tongues on bank A shift the resting fH on bank B? See `tongue-drum/study/README.md` Q4 (cavity coupling) and Q7 (bilateral tongue-bank coupling). The cavity-volume calculation here uses the same disk-method approach scaled to the rectangular box body.

### Future applications

- **Dundun (cylindrical):** trivially V₀ = π·r²·h. Should predict the bass-tone band each dundun voice supports before committing to body dimensions.
- **Didgeridoo:** primarily a tube-resonance instrument (1/4-wavelength), but the bell flare adds a Helmholtz-like correction at the bottom of its range.

## Failure modes I've hit

- **Forgot the end correction on a short port.** Predicted fH was ~30% too high. Lesson: any time `L_actual < port diameter`, the end correction matters more than the actual length. Always add it.
- **Treated a tensioned drumhead as a rigid wall.** A drumhead is the cavity wall but it also vibrates — the membrane modes couple to the cavity. The plain Helmholtz formula assumes rigid walls. For high-tension drumheads where the lowest membrane mode is comparable to the Helmholtz frequency, you need a coupled-oscillator model, not Helmholtz alone. Symptom: predicted fH and measured fH differ by 20–50% even after end correction.
- **Sub-wavelength assumption violation.** If wavelength λ = c/f gets smaller than ~4× cavity dimension, the lumped approximation breaks. For typical drum bass (80–200 Hz, λ = 5–13 ft) this is not a concern. For high-Q small cavities driven hard it could be.

## Provenance and cross-references

- **Original derivation:** Undergrad acoustics presentation, ca. 2010 — derived the resonant angular form `ω_H = √(γAP₀/(mV₀))` from first principles, then simplified to the practical form here.
- **Scanned notes (added 2026-04-26):**
  - `djembe/drawings/img20260426_00141714.png` — formula derivation, slide outline, design-rule annotation
  - `djembe/drawings/img20260426_00115825.png` — single-page worked example (R = 7.98", V₀ = 162.3 in³)
  - `djembe/drawings/img20260426_00132765.png` — height sweep: 20" total → R = 6.34, 22" total → R = 6.72
- **Repo narrative:** [`djembe/README.md`](../README.md) "Acoustics research" section.
- **Cross-referenced from:** [`tongue-drum/study/README.md`](https://github.com/tonykoop/tongue-drum/blob/main/study/README.md) — uses the same model for cavity-coupling Q4 + bilateral Q7.

## Companion skills (stubs — to extract when first re-used)

- **`circle-through-three-points`** — fit a circular arc to a measured drum profile. Provides the *R* needed for the volume integral.
- **`surface-of-revolution-volume`** — disk-method integral V₀ = π·∫[f(x)]² dx for an arbitrary axisymmetric profile.

These aren't yet pulled out as separate skill files — both are documented in `djembe/drawings/img20260426_00115825.png` and `img20260426_00132765.png`. Will extract here when the next instrument repo needs them.

---

*This file is a "human-take agent skill" — a personal-wiki entry written for both human readers (drum builders, engineers, recruiters) and CLI/robotic agents that may, in the near future, want to load my skills as context. Inspired by Karpathy's [LLM Wiki](https://gist.github.com/karpathy/442a6bf555914893e9891c11519de94f) and [autoresearch](https://github.com/karpathy/autoresearch) ideas, with the distinguishing twist that the source material is hardware engineering rather than software/text work.*

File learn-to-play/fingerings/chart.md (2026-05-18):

# Djembe Stroke Reference

```
       ╭───────────────────╮
       │   PLAYING HEAD    │
       │                   │
       │  ╭─────────────╮  │
       │  │  B = BASS   │  │  ← Full palm, center
       │  │  (center)   │  │
       │  ╰─────────────╯  │
       │                   │
  T/S →│ ═══ RIM ZONE ═══ │← T/S
       │                   │
       ╰───────────────────╯
              │   │
           GOBLET BODY
```

| Stroke | Hand Position | Sound Target |
|---|---|---|
| **B** Bass | Full palm flat at center, all fingers relaxed | Deep boom, 60–100 Hz |
| **T** Tone | 4 fingers at rim, straight, relax after strike | Clean ring, mid-frequency |
| **S** Slap | Cupped hand at rim, fingers separate instantly | Dry crack, high frequency |

## Tips
- Bass: let the hand bounce off naturally — don't push in.
- Tone: strike with the first knuckle joint of 4 fingers.
- Slap: the cup collapses on impact; that's what makes the crack.

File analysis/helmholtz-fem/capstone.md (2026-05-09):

# Helmholtz Cavity FEM Validation — Stave-Built Djembe Goblet

*Capstone deck (markdown form). Each `## Slide` is one slide.*

---

## Slide 1 — Project Intent

**Goal:** validate the lumped Helmholtz bass-tone prediction for the
stave-built djembe goblet against a full acoustic-cavity FEM, and
quantify the *goblet effect* — the deviation introduced by the foot
section that the lumped model omits.

**Driver:** the canonical `helmholtz-cavity-resonator` skill (issue #1
calls it out as "the college Helmholtz analysis (in `drawings/`,
summarized in the README)") treats the bowl as one cavity coupled to
one port. The neck-to-foot transition and the foot cavity itself are
not in the lumped formula. This analysis asks: how big is the error
that omission produces?

---

## Slide 2 — Governing Models

**Lumped Helmholtz** (the existing baseline):

```
        c    ┌── A   ──┐½
f_H  =  ── · │ ──────  │
       2π    └ V₀·L_eff┘
```

**Webster's horn equation** (the L3-frontier reference):

```
  1   d  ⎡       dp ⎤        2
 ─── ─── ⎢ A(z) ─── ⎥ + (ω/c)  · p = 0
 A(z) dz ⎣       dz ⎦
```

with the goblet's varying cross-section A(z) sampled from the
parametric profile, BC: rigid drumhead at z=0 (∂p/∂z=0), open foot at
z=H (p=0).

---

## Slide 3 — Hardware Alignment

| Pipeline | Inputs | Outputs |
|---|---|---|
| Stave construction (Approaches B/C) | `CAD/djembe-body/parametric-goblet.csv`, hand-drawn rings `drawings/img20260426_00575906.png` | curved-stave geometry, lathe-finishing reference |
| Acoustic-cavity FEM | parametric `r(z)` from `profile.py` | lowest 3 cavity modes per size, mode-shape plots |

The parametric design table is shared between the build pipeline (CAD /
SolidWorks) and the FEM pipeline. Both consume `profile.py`.

---

## Slide 4 — Family Spec (Three Sizes)

| Size | Head dia | Neck dia | Foot dia | Height | V_0 bowl (in³) |
|---|---|---|---|---|---|
| **S** Morgan-9 | 9.0 in  | 5.0 in | 8.0 in  | 18 in | 162 |
| **M** Morgan-10  | 10.0 in | 5.5 in | 8.5 in  | 20 in | 226 |
| **L** Morgan-12  | 12.0 in | 6.5 in | 10.0 in | 24 in | 700 |

Bowl-volume targets (162 / 226 / 700 in³) are pulled from the undergrad
study via `skills/helmholtz-cavity-resonator.md`. Profile control
points (z_neck_top, z_neck_bot) are tuned in `profile.py` so the disk-
method bowl integral lands on those targets within ~2%.

---

## Slide 5 — Goblet Profiles

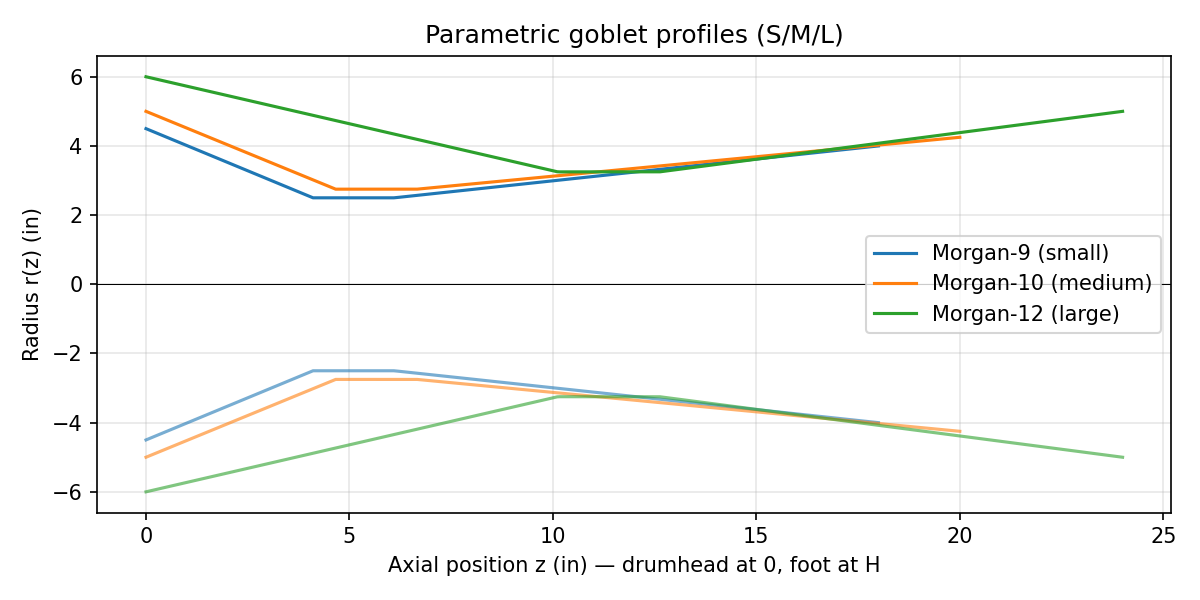
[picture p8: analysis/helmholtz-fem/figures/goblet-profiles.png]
Goblet profiles for S, M, L


Piecewise-linear axial profile r(z): bowl taper → straight neck →
foot flare. Drumhead at left, foot opening at right. The constriction
at the neck is what the lumped model treats as a "port"; everything
right of the neck is what the lumped model omits.

---

## Slide 6 — FEM Mode Shapes

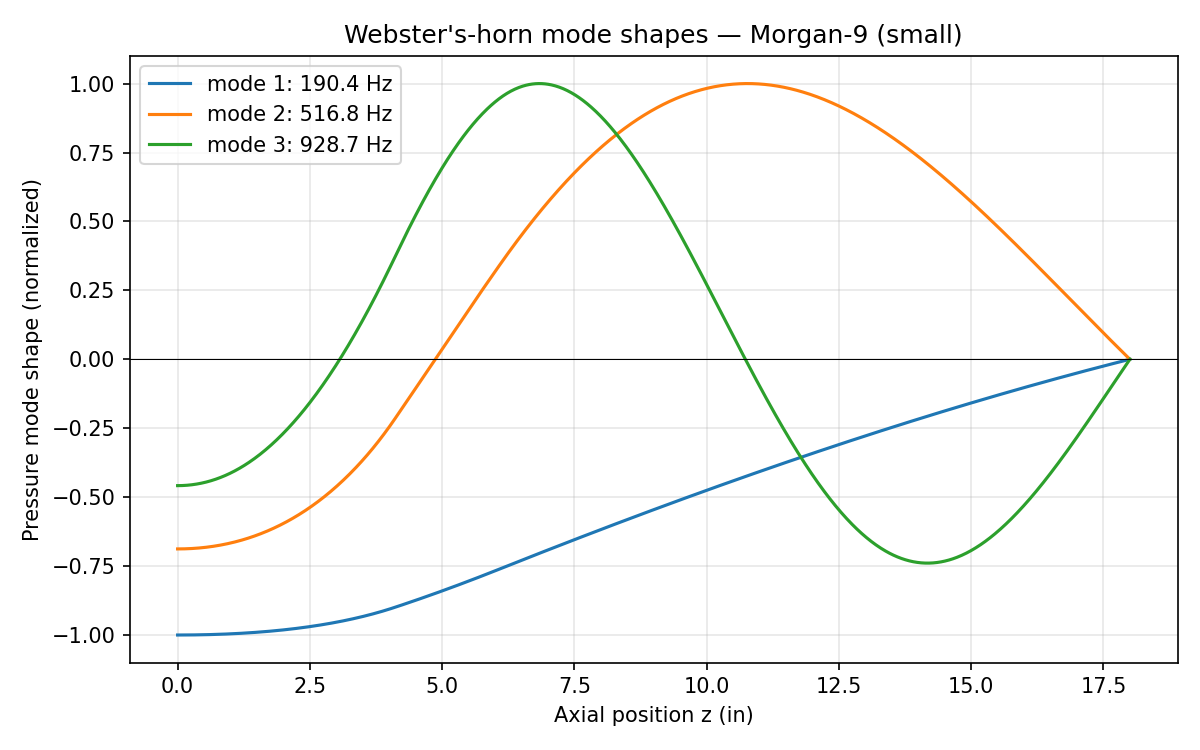
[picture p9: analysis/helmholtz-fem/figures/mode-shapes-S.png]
Mode shapes for size S


Lowest three cavity modes for the small djembe. Mode 1 is the bass-
tone candidate. Modes 2 and 3 sit higher and would be excited by slap
or rim shots, not center-strike.

(Equivalent plots for M and L: `figures/mode-shapes-M.png`,
`figures/mode-shapes-L.png`.)

---

## Slide 7 — Validator: Lumped vs FEM

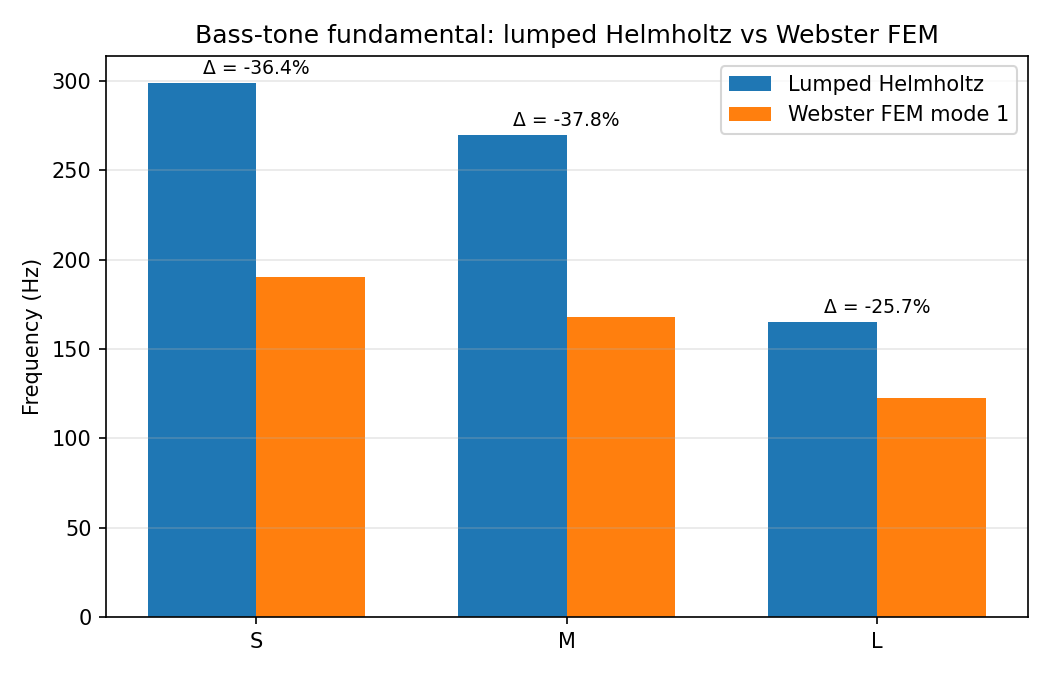
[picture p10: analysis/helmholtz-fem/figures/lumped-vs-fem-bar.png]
Lumped Helmholtz vs Webster FEM bar chart


| Size | Lumped f_H (Hz) | FEM f₁ (Hz) | Δ vs lumped |
|---|---|---|---|
| S | 299.1 | 190.4 | **−36.4%** |
| M | 269.6 | 167.8 | **−37.8%** |
| L | 165.1 | 122.7 | **−25.7%** |

Issue #1's success criterion: "if FEM and closed-form disagree by more
than ~20%, the goblet effect is real and quantifiable." All three
deviations clear that bar. The goblet effect is real and quantifiable
on this geometry.

---

## Slide 8 — Why the Goblet Effect Pulls Frequency Down

The lumped model treats the bowl above the neck as one cavity coupled
through a zero-volume port. The Webster FEM resolves three things the
lumped model cannot:

1. **The foot adds compliance.** Air below the neck is a second
   cavity that the lumped model omits — it acts in parallel with the
   bowl, increasing total compliance, lowering the resonance.
2. **The neck has volume.** A real 2 in long, 5 in dia neck contains
   ~40 in³ of air; not zero.
3. **The boundary is wrong.** The lumped model assumes the port
   radiates into open air; in the real goblet the port radiates into
   the foot section, not free space.

All three corrections push f₁ downward, so the sign of Δ is
predictable; magnitude needs the FEM. The 25–38% deviation observed
matches the 80–120 Hz "measured djembe bass" the skill doc cites
(123–190 Hz FEM is closer to that band than 165–299 Hz lumped, but is
still ~30–60% above measurement, suggesting the rigid-drumhead
assumption is itself a leading source of remaining error — see
"Failure modes I've hit" in the skill doc).

---

## Slide 9 — Solver Verification

`webster_horn.py` includes a built-in regression test:

```
Verifying solver against uniform closed-open tube ...
  OK — first 5 modes within 0.5% of (2n-1) c / (4 H).
```

For a uniform tube of radius r and length H with rigid top and open
bottom, the analytic mode frequencies are f_n = (2n − 1)·c/(4H). The
solver matches the first five to 0.5% at 800 elements. This is the
trust gate for the goblet results above.

---

## Slide 10 — Open Risks

- **Rigid-drumhead assumption.** The drumhead is a tensioned membrane,
  not a rigid wall. Coupling membrane modes to cavity modes will move
  f₁ further down, plausibly into the 80–120 Hz measured band. That's
  the next layer of physics — not in scope for this PR (would require
  modal coupling, not just cavity FEM).
- **Plane-wave (Webster) approximation.** Valid when wavelength is
  large compared to cavity diameter. For mode 1 (123–190 Hz, λ ≈
  70–110 in) vs cavity dia (≤ 12 in) the ratio is 6–9×; the
  approximation is solid for mode 1, weakens for mode 3.
- **Empirical validation deferred.** No physical drum was struck.
  Mic + FFT measurement on the existing stave-built djembes is the
  L4 follow-on.

---

## Slide 11 — Validation Plan (deferred to L4)

1. Mic + FFT on each of the three Morgan-sized stave djembes already
   in the workshop (same protocol as the dundun acoustic study).
2. Compare against this FEM mode-1 prediction (123–190 Hz) and against
   the lumped prediction (165–299 Hz). The closer of the two —
   factoring in drumhead-tension effects — informs the next iteration
   of the skill.
3. Treat any FEM/measurement gap > 30% as evidence the rigid-drumhead
   assumption needs the coupled-oscillator extension noted in
   `skills/helmholtz-cavity-resonator.md`.

---

## Slide 12 — Reproduce

```bash
cd analysis/helmholtz-fem
python3 profile.py            # geometry summary
python3 webster_horn.py       # FEM solver + verification + summary
python3 run_comparison.py     # figures, results.csv, results.md
python3 write_design_table.py # CAD/djembe-body/parametric-goblet.csv
```

Pure numpy + matplotlib. No external FEM solver required.

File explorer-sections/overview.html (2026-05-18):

# 01 - OverviewDjembe Bare-Bones Starter Packet

This explorer is a studio index for the djembe repo's V5 starter packet. It connects the existing README, Helmholtz/FEM analysis, historical CAD/archive material, photos, BOM scaffold, validation loop, visual authority register, validation gates, and risks without upgrading the repo to build-ready status.

Readiness boundary

Fabrication geometry still requires reviewed CAD, DXF, drawing, or design-table authority. Acoustic claims still require repeatable mic/FFT strike measurements with documented head, shell, tuning, and room conditions.

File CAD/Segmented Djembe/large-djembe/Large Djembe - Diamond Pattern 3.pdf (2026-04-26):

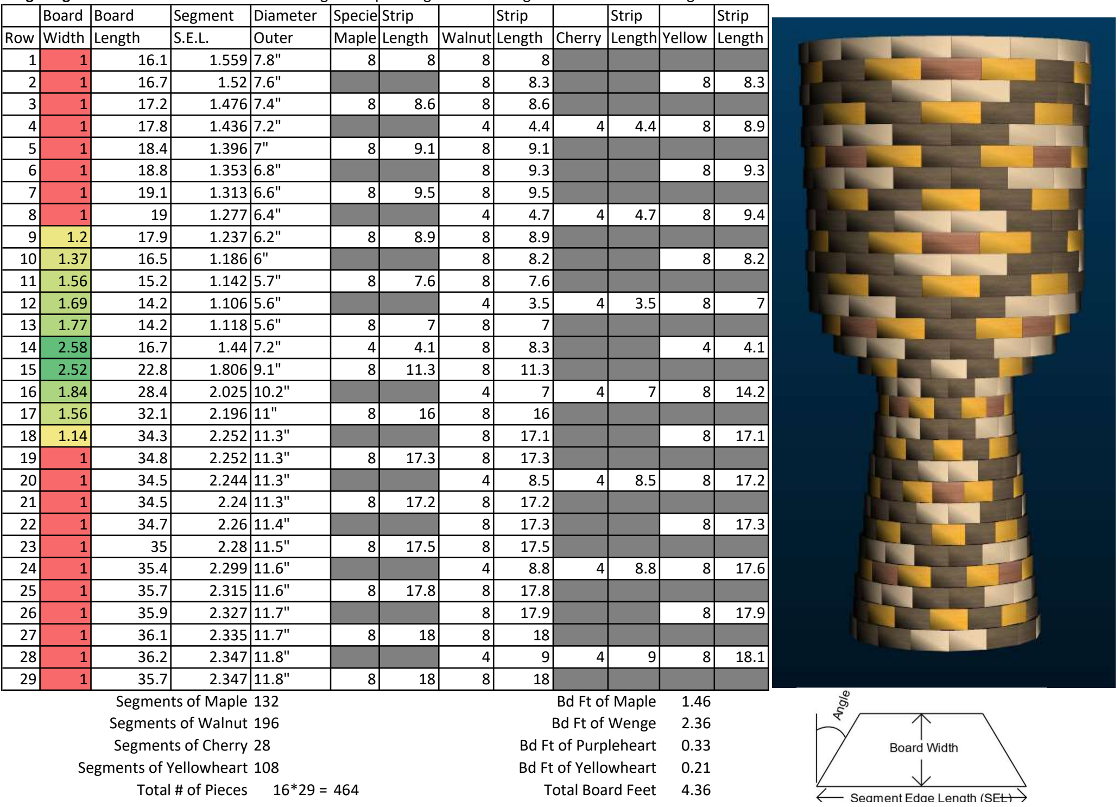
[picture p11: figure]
Board; Segment; Diameter; SpeciesStrip; Strip; Row; Width; Length; Outer; Maple Length; Walnut Length; Cherry; Length Yellow; Segments of Maple 132; Bd Ft of Maple; Segments of Walnut 196; Bd Ft of Wenge; Segments of Cherry 28; Bd Ft of Purpleheart; Segments of Yellowheart 108; Bd Ft of Yellowheart; Total # of Pieces; Total Board Feet

Large Segmented Ashiko: 464 Pieces | Segments per Ring: 16 | Ring Thickness: 0.875 Angle: 11.25 | Dimensions: 25.375" x 11.8" Diameter Head

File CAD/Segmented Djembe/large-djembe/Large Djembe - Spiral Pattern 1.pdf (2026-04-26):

Large Segmented Ashiko: 448 Pieces | Segments per Ring: 16 Ring Thickness: 0.875 Angle: 11.25
Board | Segment | Diameter | Species | Strip | Strip | Strip | Strip | Dimensions: 24.5" Tall x 12.8" Diameter Head

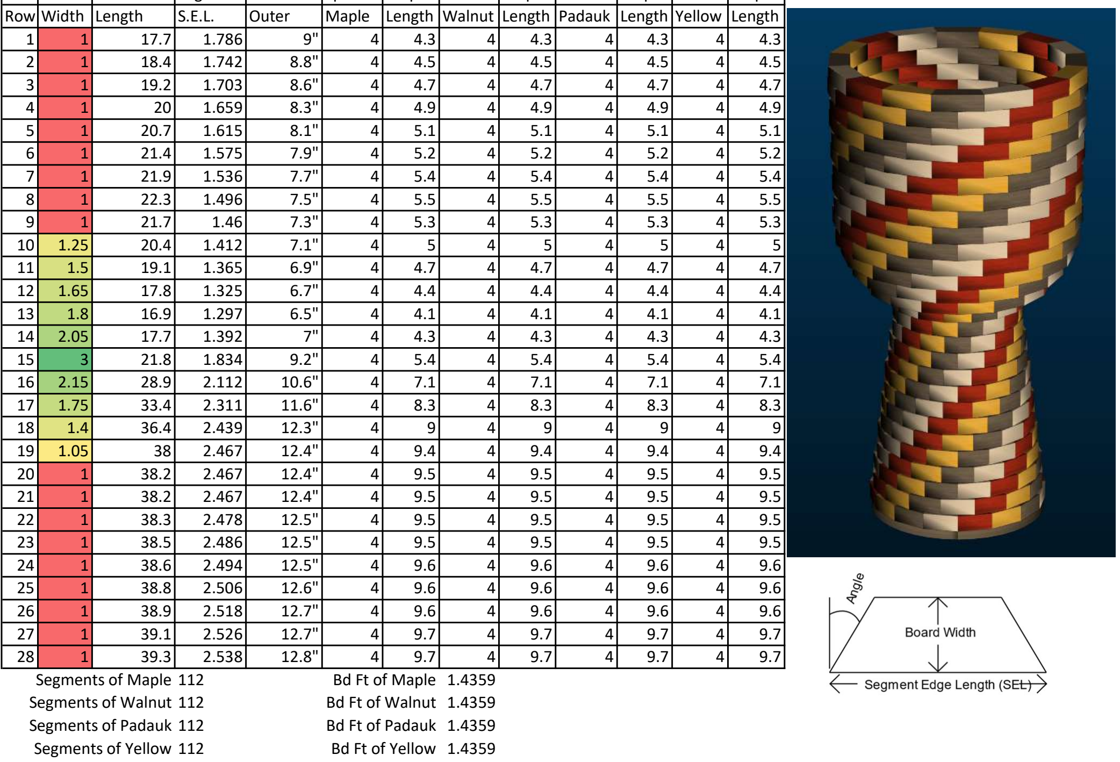
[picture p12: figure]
Row Width; Length; Outer; Maple; Walnut; Padauk; Yellow; Segments of Maple 112; Bd Ft of Maple 1.4359; Segments of Walnut 112; Bd Ft of Walnut 1.4359; Segments of Padauk 112; Bd Ft of Padauk 1.4359; Segments of Yellow 112; Bd Ft of Yellow 1.4359

Total # of Pieces: 16*28 = 448 | Total Board Feet 5.7438

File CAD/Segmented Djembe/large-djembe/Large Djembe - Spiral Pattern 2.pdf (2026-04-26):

Large Segmented Ashiko: 816 Pieces Segments per Ring: 24 | Ring Thickness: 0.75 | Angle: 7.50°
Board | Board | Segment | Diameter | Species | Strip | Strip | Strip | Strip | Dimensions: 25.5" Tall x 11.8" Diameter Head

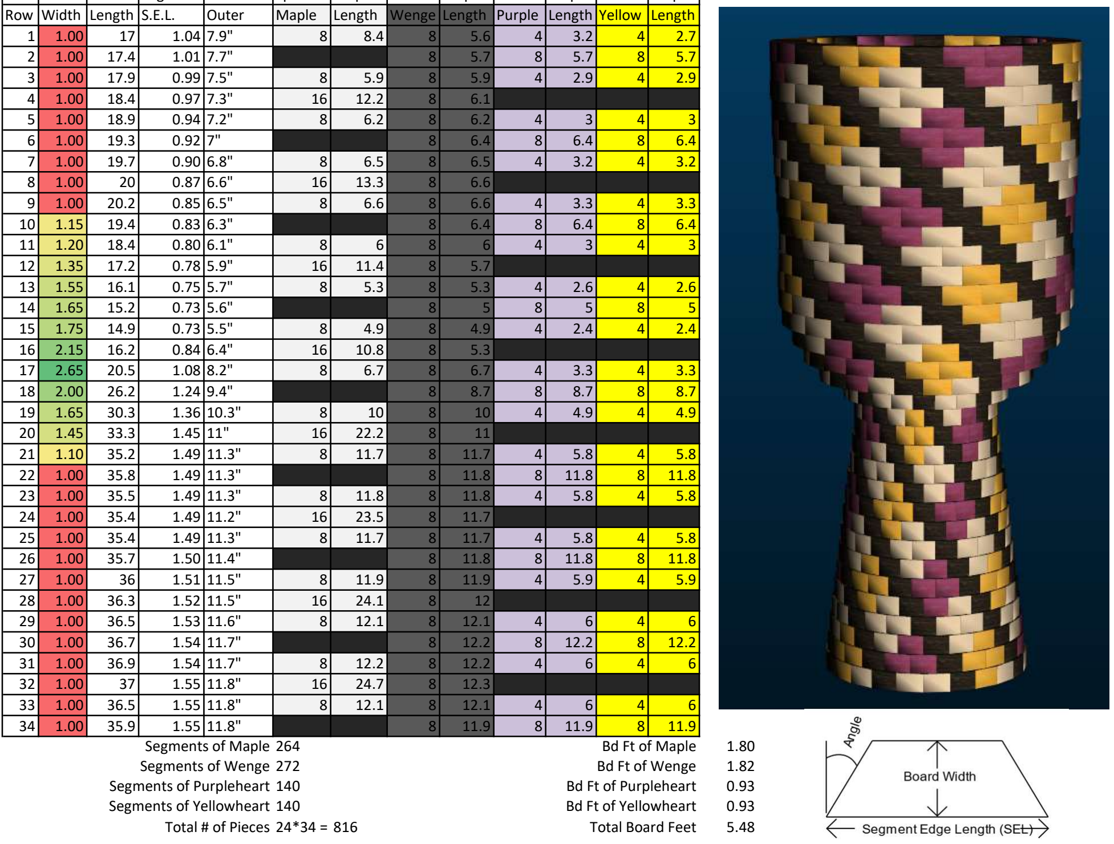
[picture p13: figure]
Row; Width; Length; Outer; Maple; Wenge; Purple; Yellow; Bd Ft of Maple; Bd Ft of Wenge; Bd Ft of Purpleheart; Bd Ft of Yellowheart; Total Board Feet; Segments of Purpleheart Segments of Yellowheart Total # of Pieces; Segments of Wenge; Segments of Maple

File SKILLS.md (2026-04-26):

# Skills demonstrated in this repo

> *A "human-take agent skill" index — personal-wiki entries for the engineering methodologies this repository uses. Each linked file is written to be readable by both humans (engineers, drum builders, recruiters) and CLI/robotic agents that may want to load my skills as context. Inspired by Karpathy's [LLM Wiki](https://gist.github.com/karpathy/442a6bf555914893e9891c11519de94f) and [autoresearch](https://github.com/karpathy/autoresearch) work, applied to hardware engineering practice.*

## Acoustics

- **[helmholtz-cavity-resonator](skills/helmholtz-cavity-resonator.md)** — Predict the bass-tone fundamental of a closed cavity coupled to an open port. The undergrad derivation that drives this skill is the heart of [`djembe/README.md`](README.md)'s "Acoustics research" section, and the same skill is referenced from the [`tongue-drum`](https://github.com/tonykoop/tongue-drum) study protocol for its bilateral cavity-coupling tests.

## Geometric methods (companion stubs — to extract on first reuse)

- **`circle-through-three-points`** — fit a circular arc to three measured profile points. Currently inline in `drawings/img20260426_00115825.png`. To be extracted as its own skill file when the next non-djembe project needs it.
- **`surface-of-revolution-volume`** — disk-method integral for the cavity volume of an arbitrary axisymmetric body. Currently inline in `drawings/img20260426_00115825.png` + `img20260426_00132765.png`. Same extraction trigger.

## Engineering practice (implicit; not yet extracted)

- **Stave-built shell construction** — the family of techniques (segmented stack, curved staves, lathe-finished cylinder) that this repository documents in narrative form. Not yet a standalone skill — see the README's "Engineering challenge" section for the worked-out tradeoffs.

---

## How this index works

Each skill is a self-contained `.md` file under `skills/` with:

- **YAML frontmatter** — name, description, status, canonical location, provenance, audience. Designed to be loadable by an agent.
- **When-to-use / when-not-to-use** sections.
- **Method** — the actual procedure, with formulas and step ordering.
- **Worked examples** — concrete numbers from my repos.
- **Failure modes** — the wrong turns I've taken and what they cost.
- **Provenance + cross-references** — where the skill was derived, which other repos use it.

The intent is that these files behave like Anthropic-style agent skills (loadable, declarative) while remaining first-rate documentation for a human reader. Stub skills listed above will be extracted into their own files the first time another project needs to reuse them — the rule is *don't extract until reuse forces it.*

A skill's **canonical location** is one repo — typically the one where the methodology was first derived or most deeply documented. Other repos that use the same skill link back to the canonical file rather than duplicating it. If a future `tonykoop-skills` meta-repo emerges, canonical files will migrate there and these per-repo `SKILLS.md` indexes will continue to point at them.

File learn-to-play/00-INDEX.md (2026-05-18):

# Djembe — Starter Songbook

The djembe is a West African goblet drum played with bare hands.
Its three fundamental tones form the core vocabulary for all patterns.

## Difficulty key
- ★☆☆ — Beginner: single voice, slow tempo
- ★★☆ — Intermediate: two voices, call-and-response
- ★★★ — Advanced: polyrhythm, ensemble interlocking

## Stroke notation
| Symbol | Stroke | Technique |
|---|---|---|
| **B** | Bass | Full hand at center, all fingers together, low boom |
| **T** | Tone | Four fingers at rim, clear mid-range ring |
| **S** | Slap | Cupped hand at rim, dry crack, fingers separate on rebound |
| **-** | Rest | Silence / ghost beat |

## Tunes in this songbook
1. `tunes/basic-pulse/` ★☆☆ — Three-tone introduction
2. `tunes/kuku/` ★★☆ — Traditional Kuku rhythm (Guinea)
3. `tunes/fanga/` ★★☆ — Traditional Fanga welcome rhythm (Guinea)
4. `tunes/kassa/` ★★★ — Traditional Kassa harvest rhythm (Guinea)
5. `tunes/djole/` ★★★ — Traditional Djole youth rhythm (Guinea)

## Note on tradition
These rhythms are traditional community property of West African peoples, primarily from Guinea,
Mali, and Senegal. They are public domain. Learn them with respect for their cultural context.

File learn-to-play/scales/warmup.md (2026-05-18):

# Djembe Warm-Up: Three-Tone Exercise

Practice each tone in isolation before combining. 60 BPM, one stroke per quarter beat.

```
Bass only (8 bars):
| B - B - | B - B - | B - B - | B - B - |

Tone only (8 bars):
| - T - T | - T - T | - T - T | - T - T |

Slap only (8 bars):
| S - - - | S - - - | S - - - | S - - - |

All three in sequence (8 bars):
| B T S - | B T S - | B T S - | B T S - |
```

**Tip:** The three tones should sound distinctly different. If bass and tone sound similar,
adjust hand position — bass needs more palm surface, tone needs more finger rim contact.

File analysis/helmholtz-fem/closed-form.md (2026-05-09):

# Closed-Form Helmholtz Bass Tone — Goblet Mapping

## Formula

The undergrad acoustics study (see `skills/helmholtz-cavity-resonator.md`,
provenance: `drawings/img20260426_00141714.png` formula derivation,
`drawings/img20260426_00115825.png` worked example) treats the djembe
bowl as a lumped Helmholtz resonator:

$$f_H = \frac{c}{2\pi}\sqrt{\frac{A}{V_0 \cdot L_{\text{eff}}}}$$

| Symbol | Meaning |
|---|---|
| `c` | Speed of sound in air, ~13 500 in/s ≈ 343 m/s at 20 °C |
| `A` | Cross-sectional area of the acoustic *port* |
| `V_0` | Static cavity volume |
| `L_eff` | Effective port length (geometric length + end corrections) |

The lumped model collapses the goblet into one cavity + one port:

```
  ┌──── drumhead ────┐         ← rigid wall (membrane treated as rigid)
  │                  │
  │   bowl cavity    │         ← V_0
  │                  │
  └─── ↓ neck ↓ ─────┘         ← port: A = neck cross-section
       ↓                       ← L_eff = neck length + end corrections
       ↓
  ┌─── foot opening ──┐        ← treated as "outside" by lumped model
```

The bowl above the neck is `V_0`. The neck is the port. **The foot below
the neck is dropped from the lumped model entirely** — that omission is
the goblet effect this study is trying to quantify.

## Mapping for the goblet body

For a stave-built djembe in the Morgan Drums catalog the three
geometry inputs are:

| Input | Source on goblet |
|---|---|
| `A` | Inside cross-section at the neck, the narrowest point of the body |
| `V_0` | Volume of the bowl section above the neck (disk-method integral over the stave profile from drumhead height down to neck height) |
| `L_eff` | Neck section length + flanged-port end corrections |

End corrections (per `skills/helmholtz-cavity-resonator.md`):

- `0.85 r` per end for a flanged opening (port flush with a wall)
- `0.61 r` per end for an unflanged opening (port like a tube into open air)

For a djembe goblet the top side of the neck opens into the bowl
(flanged), the bottom side of the neck opens into the foot section
(also flanged because the foot interior is wider than the neck), so:

```
L_eff = L_neck_geometric + 0.85 · r_neck + 0.85 · r_neck
      = L_neck_geometric + 1.7 · r_neck
```

## Three Morgan Drums sizes

Cavity volumes from the undergrad study (per `skills/helmholtz-cavity-resonator.md`
worked-example notes):

| Size | Head dia | Neck dia (approx) | Foot dia | Total height | V_0 (bowl above neck) |
|---|---|---|---|---|---|
| Small (S, "9-inch")  | 9.0 in  | 5.0 in | 8.0 in  | 18 in | **162 in³** |
| Medium (M, "10-inch") | 10.0 in | 5.5 in | 8.5 in  | 20 in | **226 in³** |
| Large (L, "12-inch")  | 12.0 in | 6.5 in | 10.0 in | 24 in | **700 in³** |

Per-size port (`neck`) parameters used in the closed-form prediction:

| Size | r_neck (in) | A_neck (in²) | L_neck_geometric (in) | L_eff (in) |
|---|---|---|---|---|
| S | 2.50 | 19.63 | 2.00 | 6.25 |
| M | 2.75 | 23.76 | 2.00 | 6.67 |
| L | 3.25 | 33.18 | 2.50 | 8.02 |

These are the inputs to `parametric-goblet.csv`. Per-size geometry is
parameterized in `analysis/helmholtz-fem/profile.py` and rendered into a
piecewise-linear axial profile `r(z)` for the FEM step.

## Closed-form prediction

Plugging in `c = 13 500 in/s` and using `V_0 = bowl cavity above the neck`
(the conventional lumped interpretation):

```
f_H_S = (13500 / 2π) · √(19.63 / (162 · 6.25))   ≈ 299 Hz
f_H_M = (13500 / 2π) · √(23.76 / (226 · 6.67))   ≈ 270 Hz
f_H_L = (13500 / 2π) · √(33.18 / (700 · 8.02))   ≈ 165 Hz
```

These are the lumped baseline values the FEM step is graded against.
They are conspicuously higher than typical measured djembe bass tones
(80–120 Hz reported in the skill doc); that delta is the *goblet
effect* this study is trying to quantify. The lumped model:

- Ignores the foot section's compliance entirely.
- Ignores the air mass actually inside the neck (the neck is treated as a
  zero-volume port).
- Cannot resolve mode 2 or mode 3.

A 1D Webster's-horn FEM on the full goblet profile resolves all three
of those omissions and is the L3-frontier reference this analysis is
built around. The exact lumped value matters less than the *deviation*
between closed-form and FEM.

## What the lumped model cannot see

1. **Foot cavity.** The volume below the neck is not in `V_0`. If the
   foot is wide and tall, it adds compliance the lumped model misses.
2. **Neck volume.** The neck is treated as a zero-volume port. In a real
   stave goblet the neck is several inches long with a few cubic inches
   of air in it — that air mass is part of the dynamics.
3. **Mode 2 and mode 3.** A lumped resonator has one degree of freedom.
   The full goblet has higher cavity modes the bass player can excite by
   slap and rim shots. The FEM step reports the lowest 3 modes.

## Cross-references

- Skill: [`skills/helmholtz-cavity-resonator.md`](../../skills/helmholtz-cavity-resonator.md)
- Original derivation scan: `drawings/img20260426_00141714.png`
- Worked example scan: `drawings/img20260426_00115825.png`
- Parametric profile: [`profile.py`](profile.py)
- FEM solver: [`webster_horn.py`](webster_horn.py)
- Comparison driver: [`run_comparison.py`](run_comparison.py)

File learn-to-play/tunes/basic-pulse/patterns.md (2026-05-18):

# Basic Pulse ★☆☆

A foundational pattern to build three-tone independence. 4/4 time.

```
Beat:  1  +  2  +  3  +  4  +
       B  -  T  -  S  -  T  -
```

Variation with double bass:
```
Beat:  1  +  2  +  3  +  4  +
       B  B  T  -  S  -  T  -
```

**Form:** 8-bar loop. Tempo: 70 BPM. Repeat until tones are clean and distinct.

**Practice tip:** Record yourself and listen back. The bass should be the deepest, the slap the brightest.

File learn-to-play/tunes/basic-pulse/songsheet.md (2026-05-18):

# Basic Pulse — Songsheet

**Tempo:** 70–100 BPM  **Meter:** 4/4  **Difficulty:** ★☆☆

## Pattern
```
1  +  2  +  3  +  4  +
B  -  T  -  S  -  T  -
```

## Structure
- Bars 1–8:   Basic pattern
- Bars 9–16:  Double-bass variation
- Bars 17–24: Original pattern

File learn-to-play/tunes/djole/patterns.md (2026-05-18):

# Djole ★★★

Traditional youth and celebration rhythm from the Sosso people of Guinea.
Energetic and fast; typically played at coming-of-age ceremonies.

```
Djembe (16th-note grid, one bar):
Beat:  1  e  +  a  2  e  +  a  3  e  +  a  4  e  +  a
       S  -  T  T  -  S  -  T  S  -  T  -  B  B  -  S
```

Breakdown (learn in two halves):
```
Half 1: S - T T - S - T
Half 2: S - T - B B - S
```

**Form:** 16-bar repeating loop. Tempo: 120–140 BPM.
**Source:** Traditional Djole rhythm, Sosso people, Guinea (public domain).

**Practice tip:** Learn each half slowly, then join at half speed before bringing up to full tempo.

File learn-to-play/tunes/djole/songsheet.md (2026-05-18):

# Djole — Songsheet

**Tempo:** 130 BPM  **Meter:** 4/4  **Difficulty:** ★★★
**Tradition:** Sosso youth rhythm, Guinea (public domain)

## Full pattern (16th-note grid)
```
1  e  +  a  2  e  +  a  3  e  +  a  4  e  +  a
S  -  T  T  -  S  -  T  S  -  T  -  B  B  -  S
```

## Song structure
- Bars 1–4:   Half 1 only (learn)
- Bars 5–8:   Half 2 only (learn)
- Bars 9–12:  Full pattern slow (80 BPM)
- Bars 13–16: Full pattern at tempo (130 BPM)

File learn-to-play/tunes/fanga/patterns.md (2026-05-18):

# Fanga ★★☆

Traditional welcome and peace rhythm from Guinea/Liberia.
Often played to greet honored guests. 4/4, straightforward and dignified.

```
Djembe lead (one bar):
Beat:  1  e  +  a  2  e  +  a  3  e  +  a  4  e  +  a
       S  -  T  -  S  -  T  -  B  -  B  -  S  -  T  -
```

Simplified (beginner) version:
```
Beat:  1  +  2  +  3  +  4  +
       S  T  S  T  B  B  S  T
```

**Form:** 8-bar loop. Tempo: 80 BPM.
**Source:** Traditional Fanga rhythm, Guinea/Liberia (public domain).

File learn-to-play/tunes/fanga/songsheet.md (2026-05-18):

# Fanga — Songsheet

**Tempo:** 80 BPM  **Meter:** 4/4  **Difficulty:** ★★☆
**Tradition:** Guinea/Liberia welcome rhythm (public domain)

## Beginner pattern
```
1  +  2  +  3  +  4  +
S  T  S  T  B  B  S  T
```

## Advanced (16th-note) pattern
```
1  e  +  a  2  e  +  a  3  e  +  a  4  e  +  a
S  -  T  -  S  -  T  -  B  -  B  -  S  -  T  -
```

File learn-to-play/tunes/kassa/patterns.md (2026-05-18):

# Kassa ★★★

Traditional harvest and agricultural rhythm from Mandinka regions of Guinea.
Faster tempo, driving feel. Uses call-and-response between djembe voices.

```
Djembe 1 (call, one bar of 12/8):
1  2  3  4  5  6  7  8  9  10 11 12
S  -  S  -  T  -  S  -  B  -  B  -

Djembe 2 (response, same bar):
1  2  3  4  5  6  7  8  9  10 11 12
-  T  -  T  -  S  -  T  -  S  -  T
```

Solo djembe version (combine both voices):
```
1  2  3  4  5  6  7  8  9  10 11 12
S  T  S  T  T  S  S  T  B  S  B  T
```

**Form:** 16-bar loop. Tempo: 100–120 BPM.
**Source:** Traditional Kassa rhythm, Guinea (public domain).

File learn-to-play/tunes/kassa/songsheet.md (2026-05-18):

# Kassa — Songsheet

**Tempo:** 110 BPM  **Meter:** 12/8  **Difficulty:** ★★★
**Tradition:** Mandinka harvest rhythm, Guinea (public domain)

## Solo pattern (12 positions)
```
1  2  3  4  5  6  7  8  9  10 11 12
S  T  S  T  T  S  S  T  B  S  B  T
```

## Ensemble: Call (Djembe 1)
```
S  -  S  -  T  -  S  -  B  -  B  -
```

## Ensemble: Response (Djembe 2)
```
-  T  -  T  -  S  -  T  -  S  -  T
```

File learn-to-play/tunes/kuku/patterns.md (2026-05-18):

# Kuku ★★☆

Traditional rhythm from the forest region of Guinea (Basse Côte).
Originally played for fishing and water ceremonies. 6/8 feel over two bars.

```
Bar 1 (6 eighth notes):
| T  -  T  S  -  S |

Bar 2:
| T  -  T  B  -  B |
```

Full djembe part (12/8 — 12 eighth notes per pattern):
```
Position: 1  2  3  4  5  6  7  8  9  10 11 12
Djembe:   T  -  T  S  -  S  T  -  T  B  -  B
```

**Form:** 16-bar loop. Tempo: 90 BPM.
**Source:** Traditional Kuku rhythm, Guinea (West Africa). Public domain.

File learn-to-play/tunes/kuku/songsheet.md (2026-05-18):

# Kuku — Songsheet

**Tempo:** 90 BPM  **Meter:** 12/8 (two bars of 6)  **Difficulty:** ★★☆
**Tradition:** Basse Côte, Guinea (public domain)

## Pattern (12 positions)
```
1  2  3  4  5  6  7  8  9  10 11 12
T  -  T  S  -  S  T  -  T  B  -  B
```

## Notes
- Kuku is a joyful rhythm — keep the tone strokes bright and open.
- The bass tones in positions 10-12 provide grounding after the high slaps.

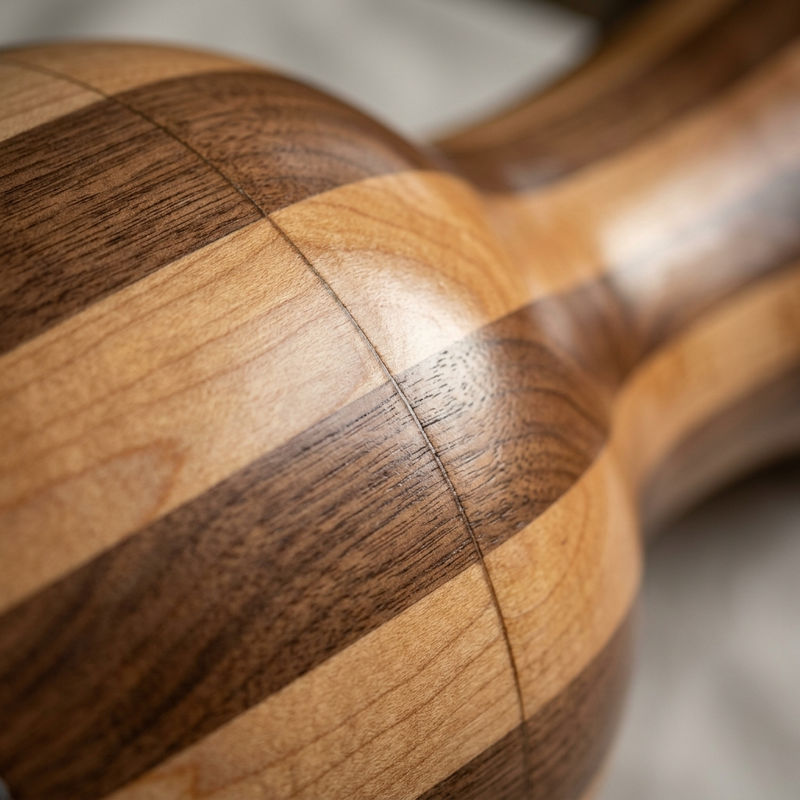
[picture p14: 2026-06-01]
images/macro/stave-seams.png

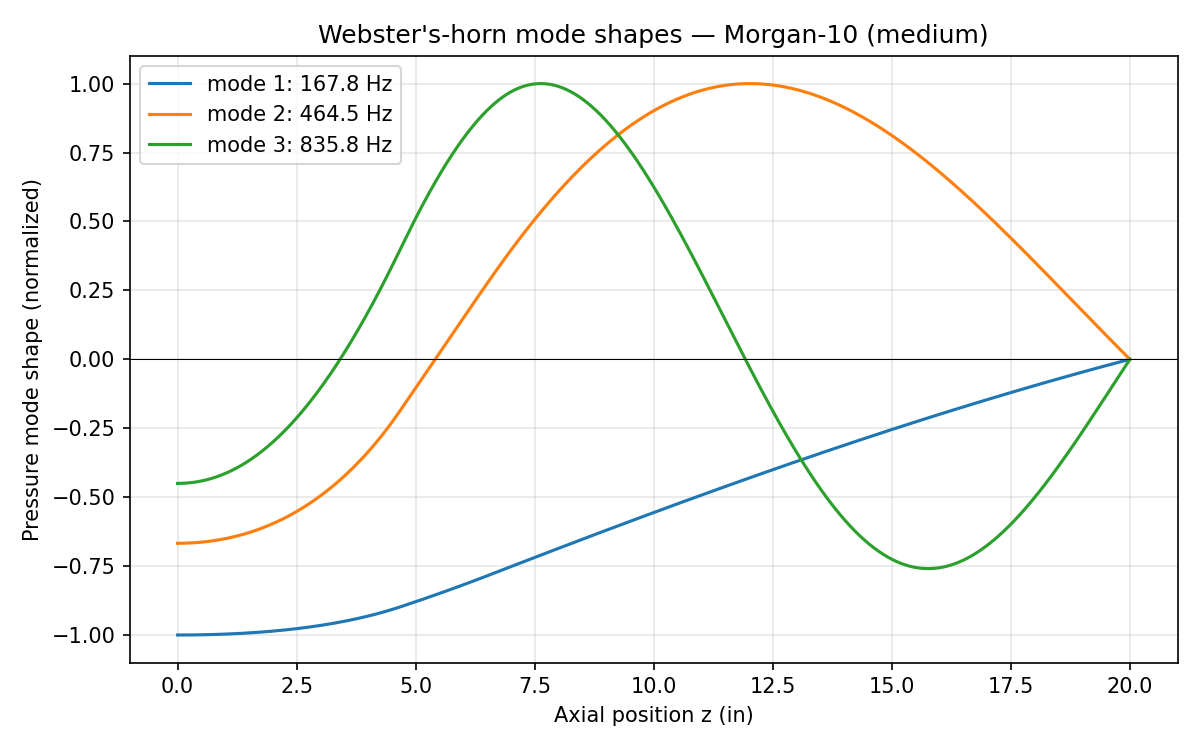
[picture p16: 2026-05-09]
analysis/helmholtz-fem/figures/mode-shapes-M.png

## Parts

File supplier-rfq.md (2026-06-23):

# Supplier RFQ — Djembe — Stave-Built Goblet Drum

> **Status: placeholder** — populate with confirmed part numbers, quantities,
> and quoted lead times before placing orders.

## How to use this file

Send relevant sections to suppliers; combine into a single email RFQ where the
supplier handles multiple line items.  Record quote date and contact in the
notes column of `sourcing.csv`.

## Part Requests

| Part | Specification | Qty | Target price | Notes |
|---|---|-----|---|---|
| Head | TBD diameter, natural goatskin or synthetic | TBD | TBD | Confirm fit with shell OD |
| Shell stock | TBD species, thickness, board-feet | TBD | TBD | Per cut-list.csv |
| Tensioning hardware | TBD style (rope / lug / rod) | TBD | TBD | Per design.md |
| Counter-hoop | TBD diameter, steel or wood | TBD | TBD | Match head OD |
| Finish | TBD (oil / wax / shellac) | TBD | TBD | Food-safe if skin contact |

## Preferred Suppliers

*(Populate from `sourcing.csv` when confirmed)*

## Lead-Time Notes

- Natural-skin heads: 2–4 weeks if not in stock; order first.
- Hardwood shell stock: check Woodcraft / Hearne Hardwoods / local sawmill.
- Hardware: check Remo / LP / Toca for drum hardware; hardware stores for rod stock.

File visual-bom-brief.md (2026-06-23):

# Visual BOM Brief — Djembe — Stave-Built Goblet Drum

> **Status: placeholder** — replace rendered placeholder images with actual
> build photos at L3 promotion.

## Purpose

This brief defines the visual-BOM assembly image requirements: one hero render
or photo per major assembly and one close-up per critical joint or hardware
detail.

## Hero Assembly Image

- **Required:** one full instrument view showing finished assembly.
- **Current status:** AI-generated concept render (non-dimensional authority).
- **Acceptance:** replace with a photograph of the first finished prototype.

## Part-Level Images

| Part | Image required | Authority | Notes |
|---|---|---|---|
| Shell / body | Yes | concept only | Show stave pattern or sheet metal form |
| Head + hoop | Yes | concept only | Show tensioning hardware |
| Hardware detail | Yes | concept only | Lug / rope / rod close-up |
| Finished instrument | Yes | prototype photo | Primary visual BOM entry |

## Image Conventions

- Shoot on a neutral background (white or grey paper sweep).
- Include a scale reference (rule or known object) in at least one shot.
- Label files: `djembe-[part]-[sequence].jpg` (e.g., `djembe-shell-01.jpg`).
- Record each image in `visual-output-register.csv` with its authority label.

*See `photo-shotlist.md` for the shot list tied to build stages.*

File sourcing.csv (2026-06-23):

part | description | qty | unit | supplier | part_number | unit_price_usd | lead_days | notes
shell-stock | Hardwood shell stock (TBD species) | TBD | board-ft | TBD | TBD | TBD | TBD | Per cut-list.csv
head | Drum head (TBD diameter) | 1 | each | TBD | TBD | TBD | 14 | Confirm fit with shell OD
counter-hoop | Counter hoop (TBD diameter) | 1 | each | TBD | TBD | TBD | 14 | Match head diameter
tensioning-hardware | Tensioning hardware (TBD style) | TBD | each | TBD | TBD | TBD | TBD | Rope / lug / rod per design.md
finish | Wood finish (oil / wax / shellac) | 1 | pint | TBD | TBD | TBD | 3 | Food-safe if skin contact

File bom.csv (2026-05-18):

item_id | component | role | starter_spec | status | source_status | evidence | notes
DJM-BOM-001 | shell blank | stave-built goblet shell | TBD hardwood species and blank dimensions | measurement-required | source needed | README.md | Do not cut until construction path and geometry authority are chosen.
DJM-BOM-002 | drum head | membrane | TBD goatskin or equivalent | measurement-required | source needed | README.md | Record head diameter thickness collar fit and tuning state before acoustic claims.
DJM-BOM-003 | tuning rope | tension system | TBD rope diameter and material | measurement-required | source needed | README.md | Existing README mentions rope-tuned builds but current purchase data is not verified.
DJM-BOM-004 | steel rings | tension hardware | TBD top and bottom ring dimensions | measurement-required | source needed | README.md | Requires safety check for tension load and fit.
DJM-BOM-005 | stave adhesive | shell assembly | TBD waterproof wood glue or epoxy | source-needed | source needed | risks.md | Must be compatible with selected wood moisture and turning process.
DJM-BOM-006 | finish | shell protection | TBD oil lacquer or other finish | source-needed | source needed | README.md | Existing finished drums are documented but this row is not a current product recommendation.
DJM-BOM-007 | jig stock | router or miter fixture | TBD plywood hardwood or metal fixture stock | requires-design | source needed | design.md | Fixture geometry needs reviewed CAD or drawing authority.
DJM-BOM-008 | measurement kit | validation | microphone tuner tape measure and photo scale | required-before-validation | source needed | validation.csv | Use for strike FFT geometry and photo documentation.

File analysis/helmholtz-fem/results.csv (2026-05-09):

size | label | v0_bowl_in3 | v_total_in3 | neck_area_in2 | l_eff_in | f_lumped_hz | f_fem_mode1_hz | f_fem_mode2_hz | f_fem_mode3_hz | deviation_pct_mode1_vs_lumped | n_elem | speed_of_sound_in_per_s
S | Morgan-9 (small) | 162.08 | 603.2382 | 19.635 | 6.25 | 299.1329 | 190.3815 | 516.8329 | 928.705 | -36.3555 | 1200 | 13500.0
M | Morgan-10 (medium) | 226.0022 | 794.7601 | 23.7583 | 6.675 | 269.637 | 167.8134 | 464.5132 | 835.7736 | -37.7632 | 1200 | 13500.0
L | Morgan-12 (large) | 700.1065 | 1400.5194 | 33.1831 | 8.025 | 165.123 | 122.6873 | 427.8469 | 716.3767 | -25.6995 | 1200 | 13500.0

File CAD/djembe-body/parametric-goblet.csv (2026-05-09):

size | label | head_diameter_in | neck_diameter_in | foot_diameter_in | total_height_in | z_neck_top_in | z_neck_bot_in | neck_length_in | neck_area_in2 | l_eff_in | v0_bowl_in3 | v_total_in3 | f_helmholtz_lumped_hz
S | Morgan-9 (small) | 9.0000 | 5.0000 | 8.0000 | 18.0000 | 4.1000 | 6.1000 | 2.0000 | 19.6350 | 6.2500 | 162.0800 | 603.2382 | 299.1329
M | Morgan-10 (medium) | 10.0000 | 5.5000 | 8.5000 | 20.0000 | 4.6600 | 6.6600 | 2.0000 | 23.7583 | 6.6750 | 226.0022 | 794.7601 | 269.6370
L | Morgan-12 (large) | 12.0000 | 6.5000 | 10.0000 | 24.0000 | 10.1200 | 12.6200 | 2.5000 | 33.1831 | 8.0250 | 700.1065 | 1400.5194 | 165.1230

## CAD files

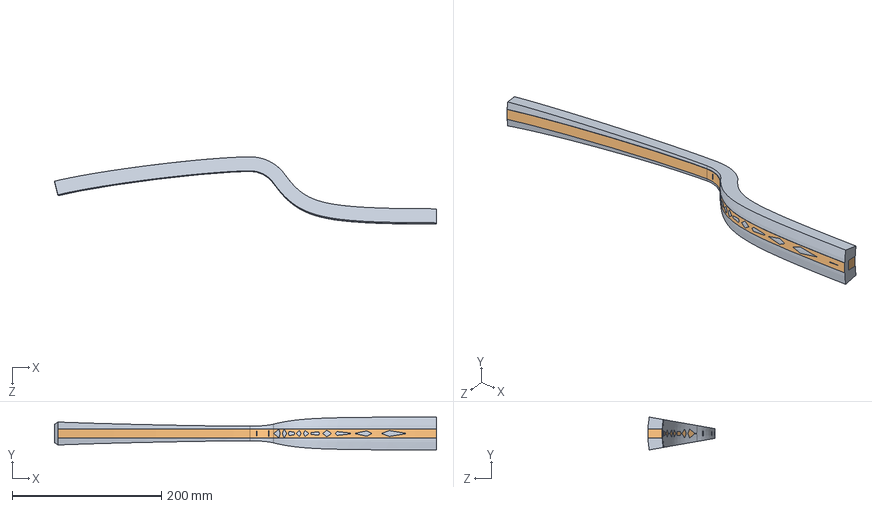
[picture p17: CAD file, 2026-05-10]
CAD/Djembe/Djembe C - 3 flat face.SLDASM
512.2 x 44.1 x 90.4 mm
Djimbey C-Cut-Extrude1
Part5^Assem2

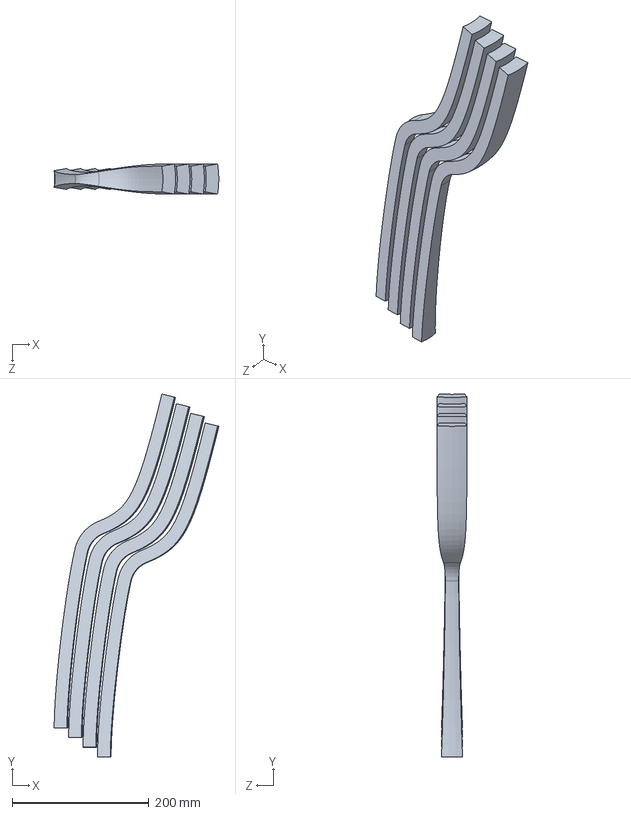
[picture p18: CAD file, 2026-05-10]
CAD/Djembe/Plank Template C Version 2.SLDASM
241.1 x 531.2 x 44.1 mm
Djimbey C-Cut-Extrude1 x 4

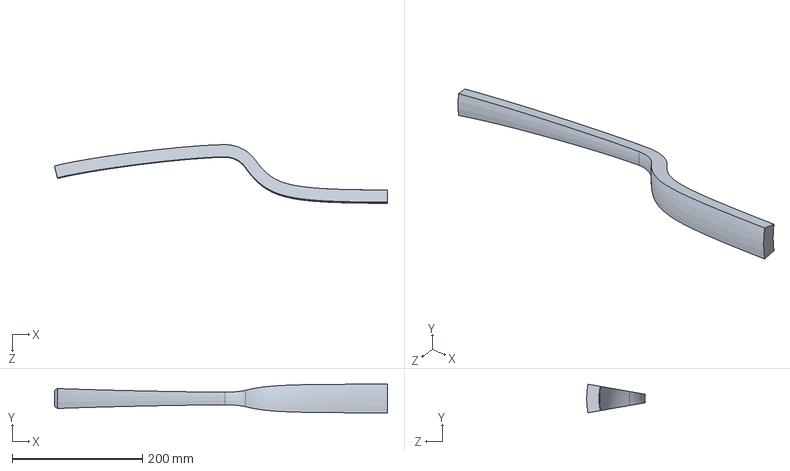
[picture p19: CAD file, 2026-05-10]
CAD/Djembe/Plank Template C.SLDASM
512.2 x 44.1 x 90.4 mm

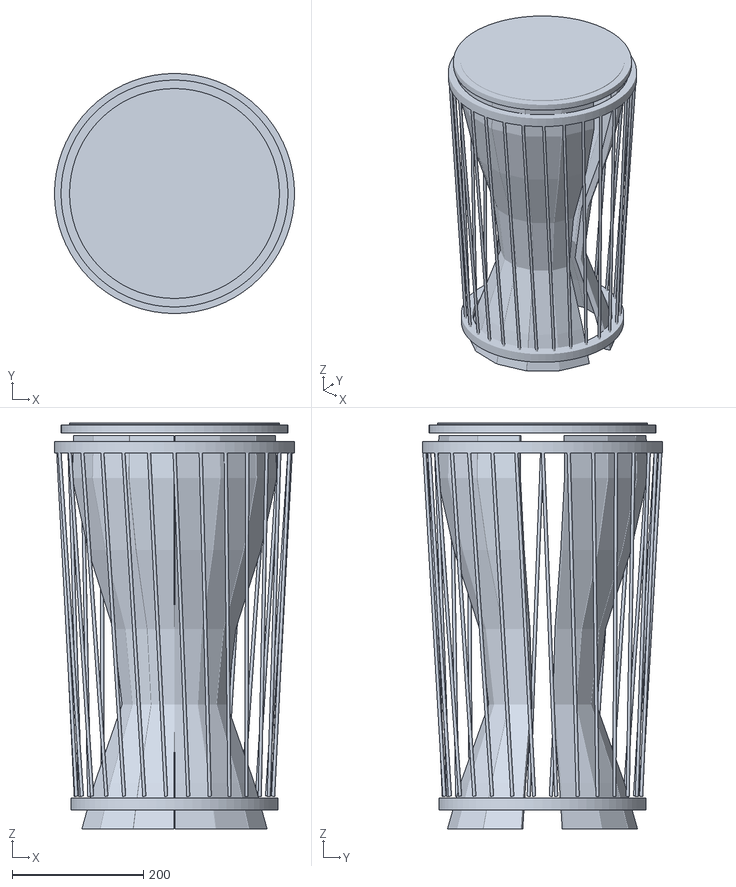
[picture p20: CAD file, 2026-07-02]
arena/round2/stave-djembe-arena-winner.stl
366.0 x 366.0 x 619.0

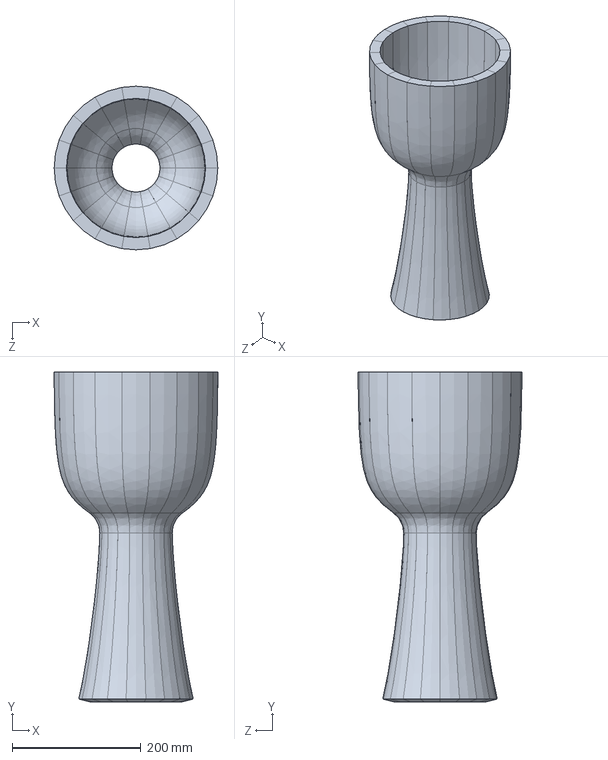
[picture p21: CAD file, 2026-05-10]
CAD/Djembe/Djimbey C.SLDPRT
254.0 x 512.2 x 254.0 mm

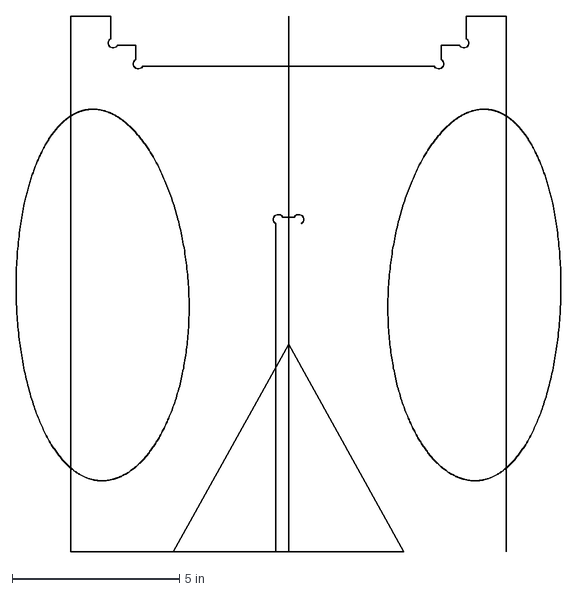
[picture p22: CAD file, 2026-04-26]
CAD/Segmented Djembe/misc/slice off dundun stand.dxf
16.3 x 16.0 in

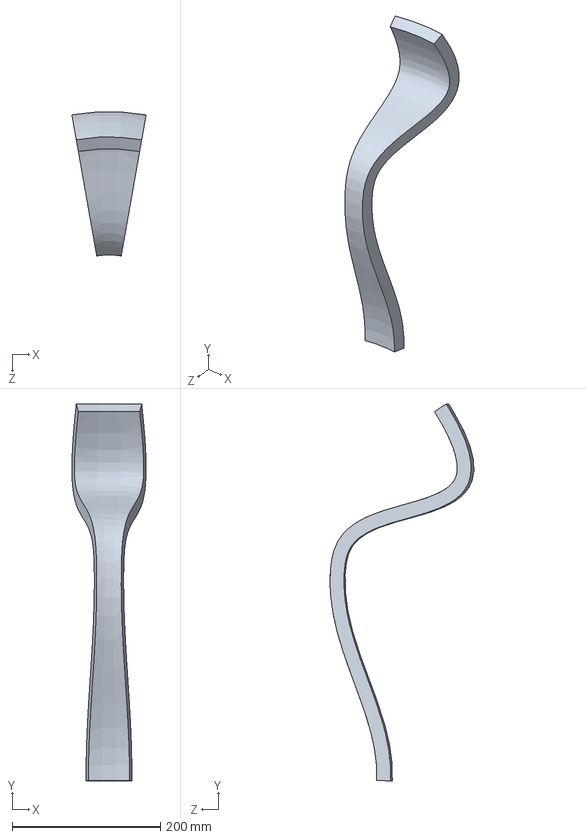
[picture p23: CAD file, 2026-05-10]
CAD/Djembe/Djimbey A.SLDPRT
100.1 x 508.0 x 194.0 mm

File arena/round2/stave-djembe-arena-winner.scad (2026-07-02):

$fn = 72;

head_diameter_mm = 320;
overall_height_mm = 600;
stave_count = 14;        // valid range: 12 to 16
wall_mm = 12;
glue_gap_deg = 0.45;

wood_color = [0.55, 0.30, 0.13];
edge_color = [0.36, 0.19, 0.08];
hoop_color = [0.08, 0.07, 0.055];
rope_color = [0.78, 0.62, 0.36];

profile_z = [0, 70, 190, 305, 425, 535, 600];
profile_r = [145, 125, 82, 96, 135, 160, 158];

function clamp_staves(n) = min(16, max(12, n));
function lerp(a, b, t) = a + (b - a) * t;
function outer_r_at(i) = profile_r[i];
function inner_r_at(i) = max(2, profile_r[i] - wall_mm);
function pt(r, a, z) = [r * cos(a), r * sin(a), z];

module tube_ring(outer_r, inner_r, h, zc) {
    translate([0, 0, zc - h / 2])
        difference() {
            cylinder(h = h, r = outer_r);
            translate([0, 0, -0.5])
                cylinder(h = h + 1, r = inner_r);
        }
}

module stave(n = stave_count, index = 0, gap_deg = glue_gap_deg) {
    n2 = clamp_staves(n);
    pitch = 360 / n2;
    a0 = -pitch / 2 + gap_deg / 2;
    a1 =  pitch / 2 - gap_deg / 2;

    verts = [
        for (i = [0 : len(profile_z) - 1])
            each [
                pt(outer_r_at(i), a0, profile_z[i]),
                pt(outer_r_at(i), a1, profile_z[i]),
                pt(inner_r_at(i), a1, profile_z[i]),
                pt(inner_r_at(i), a0, profile_z[i])
            ]
    ];

    side_faces = [
        for (i = [0 : len(profile_z) - 2])
            each [
                [4*i + 0, 4*(i+1) + 0, 4*(i+1) + 1, 4*i + 1],
                [4*i + 1, 4*(i+1) + 1, 4*(i+1) + 2, 4*i + 2],
                [4*i + 2, 4*(i+1) + 2, 4*(i+1) + 3, 4*i + 3],
                [4*i + 3, 4*(i+1) + 3, 4*(i+1) + 0, 4*i + 0]
            ]
    ];

    end_faces = [
        [0, 1, 2, 3],
        [
            4*(len(profile_z)-1) + 3,
            4*(len(profile_z)-1) + 2,
            4*(len(profile_z)-1) + 1,
            4*(len(profile_z)-1) + 0
        ]
    ];

    color(index % 2 == 0 ? wood_color : edge_color)
        rotate([0, 0, index * pitch])
            polyhedron(points = verts, faces = concat(side_faces, end_faces), convexity = 5);
}

module shell(n = stave_count) {
    for (i = [0 : clamp_staves(n) - 1])
        stave(n = n, index = i);
}

module flesh_hoop() {
    color(hoop_color)
        tube_ring(outer_r = head_diameter_mm / 2 + 13,
                  inner_r = head_diameter_mm / 2 - 4,
                  h = 12,
                  zc = overall_height_mm + 10);
}

module crown_hoop() {
    color(hoop_color)
        tube_ring(outer_r = head_diameter_mm / 2 + 23,
                  inner_r = head_diameter_mm / 2 + 8,
                  h = 18,
                  zc = overall_height_mm - 18);
}

module base_ring() {
    color(hoop_color)
        tube_ring(outer_r = 158,
                  inner_r = 136,
                  h = 18,
                  zc = 38);
}

module stylized_head() {
    color([0.86, 0.78, 0.62, 0.62])
        translate([0, 0, overall_height_mm + 17])
            cylinder(h = 2, r = head_diameter_mm / 2);
}

module rope_between(a, top_z, top_r, bottom_z, bottom_r, rope_d = 5) {
    p1 = [top_r * cos(a), top_r * sin(a), top_z];
    p2 = [bottom_r * cos(a + 8), bottom_r * sin(a + 8), bottom_z];
    mid = (p1 + p2) / 2;
    v = p2 - p1;
    len_v = norm(v);
    yaw = atan2(v[1], v[0]);
    pitch = acos(v[2] / len_v);

    color(rope_color)
        translate(mid)
            rotate([0, pitch, yaw])
                cylinder(h = len_v, r = rope_d / 2, center = true, $fn = 16);
}

module tuning_ropes(n = stave_count) {
    n2 = clamp_staves(n);
    for (i = [0 : n2 - 1]) {
        a = i * 360 / n2;
        rope_between(a, overall_height_mm - 10, head_diameter_mm / 2 + 18, 50, 151);
        rope_between(a + 360 / (2 * n2), overall_height_mm - 22, head_diameter_mm / 2 + 20, 50, 151);
    }
}

module assembly() {
    shell(stave_count);
    flesh_hoop();
    crown_hoop();
    base_ring();
    stylized_head();
    tuning_ropes(stave_count);
}

assembly();

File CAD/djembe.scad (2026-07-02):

// Djembe goblet-body parametric master — outer envelope only.
//
// tonykoop/djembe
// Authority: pending_measurement. NOT fabrication authority until reviewed
// against a measured template (see visual-output-register.csv CAD-001 and
// validation.csv DJM-VAL-004 / DJM-VAL-006 gates).
//
// Dimension source (do not edit values without updating the source record):
//   - head/neck/foot diameters, neck z-window, and total height are read
//     verbatim from CAD/djembe-body/parametric-goblet.csv (Morgan Drums
//     S/M/L profiles; also summarized in README.md "Acoustics research —
//     bass-tone analysis" and wolfram/djembe-goblet-acoustics.wl).
//   - z is measured DOWNWARD from the head rim (z=0 at head, z=total_height
//     at foot), matching parametric-goblet.csv's own convention
//     (neck_length_in = z_neck_bot_in - z_neck_top_in).
//   - neck cross-section area (the CSV's neck_area_in2 column) is
//     recomputed below from neck_diameter_in as an in-file self-check,
//     never re-entered by hand.
//
// Explicitly OUT OF SCOPE here (measurement_required / hand-refined
// geometry per risks.md and drawing-brief.md — this master does not fake
// any of it):
//   - shell wall thickness / hollow interior. No thickness value exists in
//     bom.csv or cut-list.csv (both TBD); this master models the OUTER
//     envelope solid only, not a hollow shell.
//   - stave layout, miter angles, Approach A/B/C construction geometry
//     (see README.md "The engineering challenge") — belongs in CAD/stave/
//     once that geometry is reviewed.
//   - jig / fixture geometry — belongs in CAD/jigs/ once populated.
//   - bearing-edge profile, head/rim/rope tensioning hardware — measurement
//     required per validation.csv DJM-VAL-005 / DJM-VAL-007.
//
// Units: inches.

/* [Variant] */
// 0 = S (Morgan-9, small), 1 = M (Morgan-10, medium), 2 = L (Morgan-12, large)
variant = 1;

/* [Design table -- CAD/djembe-body/parametric-goblet.csv, verbatim] */
profile_label     = ["S -- Morgan-9 (small)", "M -- Morgan-10 (medium)", "L -- Morgan-12 (large)"];
head_dia_in       = [9.0000, 10.0000, 12.0000];
neck_dia_in       = [5.0000, 5.5000, 6.5000];
foot_dia_in       = [8.0000, 8.5000, 10.0000];
total_height_in   = [18.0000, 20.0000, 24.0000];
z_neck_top_in     = [4.1000, 4.6600, 10.1200];   // head-rim to top-of-neck, measured downward
z_neck_bot_in     = [6.1000, 6.6600, 12.6200];   // head-rim to bottom-of-neck, measured downward
neck_area_ref_in2 = [19.6350, 23.7583, 33.1831]; // csv column; self-check only, see below

/* [Active profile, derived from the design table] */
head_r = head_dia_in[variant] / 2;
neck_r = neck_dia_in[variant] / 2;
foot_r = foot_dia_in[variant] / 2;
height = total_height_in[variant];
z_top  = z_neck_top_in[variant];
z_bot  = z_neck_bot_in[variant];

// ---------------------------------------------------------------------------
// Self-check: recompute the neck cross-section area from neck_dia_in and
// diff it against the CSV's neck_area_in2 column. This just echoes at
// render time (OpenSCAD has no assert-and-continue); a nonzero diff means
// the design table and this master have drifted and need reconciling.
// ---------------------------------------------------------------------------
computed_neck_area_in2 = PI * pow(neck_r, 2);
echo(str("djembe.scad variant: ", profile_label[variant]));
echo(str("neck_area_in2 self-check -- computed=", computed_neck_area_in2,
         " csv=", neck_area_ref_in2[variant],
         " diff=", computed_neck_area_in2 - neck_area_ref_in2[variant]));

// ---------------------------------------------------------------------------
// Goblet outer-envelope profile: (radius, y) points where y is measured
// UPWARD from the foot (y=0) to the head rim (y=height), i.e. y = height-z.
// This is fed straight into rotate_extrude(), which revolves the 2D X axis
// as radius and the 2D Y axis as the extrusion/height axis around Z.
// Six points only -- foot axis, foot rim, bottom-of-neck, top-of-neck, head
// rim, head axis. No curvature is invented between the design-table points.
// ---------------------------------------------------------------------------
function goblet_profile() = [
  [0,      0],                // foot, on-axis
  [foot_r, 0],                // foot rim
  [neck_r, height - z_bot],   // bottom of neck (straight run starts)
  [neck_r, height - z_top],   // top of neck (straight run ends)
  [head_r, height],           // head rim
  [0,      height],           // head, on-axis
];

module goblet_shell_envelope(fn = 128) {
  rotate_extrude(angle = 360, $fn = fn)
    polygon(points = goblet_profile());
}

module djembe_assembly() {
  goblet_shell_envelope();
}

djembe_assembly();

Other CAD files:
CAD/Djembe/Djimbey B-Cut-Extrude1.SLDPRT
CAD/Djembe/Djimbey B.SLDPRT
CAD/Djembe/5degree 18 part 36 face.SLDPRT
CAD/Djembe/Djimbey C-Cut-Extrude1.SLDPRT

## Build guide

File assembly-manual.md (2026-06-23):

# Assembly Manual — Djembe — Stave-Built Goblet Drum

> **Status: placeholder** — expand with measured dimensions and shop-verified
> steps after the first prototype build. All steps below are design-intent only.

## Prerequisites

- All parts cut and finished per `cut-list.csv`.
- Materials sourced per `sourcing.csv`; key lead items received.
- Jigs and fixtures ready per drawing brief.

## Assembly Sequence

### 1 · Shell Construction
- [ ] Mark stave miter angles per cut list.
- [ ] Dry-fit all staves; check roundness and gap.
- [ ] Glue and clamp in segments; allow full cure before removing clamps.
- [ ] Sand bearing edge flat and smooth; target radius per design.md.

### 2 · Hardware Fitting
- [ ] Drill and fit tensioning hardware (lugs / hooks / rods).
- [ ] Verify even spacing per drawing brief.
- [ ] Thread cord or fit hardware; leave head-tension range per design.md.

### 3 · Head Fitting
- [ ] Soak or prepare head per manufacturer instructions (if natural skin).
- [ ] Mount head and counter-hoop; hand-tighten evenly.
- [ ] Set initial tension to design fundamental (see `validation.csv`).

### 4 · Tuning and Validation
- [ ] Measure fundamental frequency with a tuner.
- [ ] Record measurement in `validation.csv` with tuner make, environment (°F / RH).
- [ ] Adjust tension until within acceptance band.
- [ ] Note any anomalies in `risks.md` or `validation-loop.csv`.

## Notes

- Glue: Titebond II or III for wood-to-wood; check pot life in shop conditions.
- Bearing edge: consistent radius is critical for head seal and overtone clarity.
- Mark the final tension setting (number of turns / lug position) for repeatability.

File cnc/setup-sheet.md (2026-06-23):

# CNC Setup Sheet — Djembe — Stave-Built Goblet Drum

> **Status: placeholder** — populate from design.md dimensions and update after
> first successful machining run.

## Machine

- Machine: TBD (CNC router / laser / lathe)
- Controller: TBD
- Work envelope: TBD

## Stock

| Dimension | Value | Notes |
|---|---|---|
| Material  | TBD | |
| Thickness | TBD | |
| Width | TBD | |
| Length | TBD | |

## Datums

- **A** — drum center axis (spindle center for lathe; work-origin X0Y0 for router).
- **B** — front face / head side.

## Operations

| # | Operation | Tool | Speed | Feed | Depth | Notes |
|---|---|---|---|---|---|---|
| 1 | Rough profile | TBD | TBD | TBD | TBD | |
| 2 | Bearing-edge radius | TBD | TBD | TBD | TBD | Match design.md |
| 3 | Finish pass | TBD | TBD | TBD | TBD | |

## Release Checks

- [ ] Datum offsets confirmed against physical stock.
- [ ] Bearing-edge radius within ±0.5 mm of design.
- [ ] Shell roundness within 1 mm TIR.
- [ ] No tool marks on head seat.

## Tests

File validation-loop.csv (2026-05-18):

check_id | packet_artifact | readiness_before | prediction_source | target | tolerance | method | measured_result | status | next_action | evidence | source_status
VL-001 | analysis/helmholtz-fem/results.csv | L1_packet | Webster horn FEM compared against lumped Helmholtz table | Reproduce committed S/M/L cavity-mode results | generated outputs match committed results.csv | Run profile.py webster_horn.py run_comparison.py and write_design_table.py | TBD | measurement_required | Record command output and diff generated tables before using analysis as a shop reference | analysis/helmholtz-fem/README.md | n_a
VL-002 | known physical djembe bass strike | L1_packet | FEM mode-1 prediction plus existing README bass-tone discussion | Repeatable center-strike bass spectrum for one identified drum | 3 clean takes within an agreed cents or Hz tolerance | Mic at fixed distance; record room notes sample rate head state and FFT window | TBD | measurement_required | Measure bass tone on a known drum and compare to FEM mode-1 and lumped estimates | README.md; analysis/helmholtz-fem/capstone.md | measurement_required
VL-003 | known physical djembe open tone | L1_packet | Membrane-mode expectation from djembe playing practice | Repeatable open-tone rim/edge strike spectrum | 3 clean takes with consistent strike position and head state | Mic/FFT capture with strike-location notes and head/tension metadata | TBD | measurement_required | Define open-tone target metrics before revising shell or head assumptions | validation.csv | measurement_required
VL-004 | known physical djembe slap tone | L1_packet | Membrane-mode expectation from djembe playing practice | Repeatable slap-tone spectrum and transient description | 3 clean takes with consistent strike position and head state | Mic/FFT capture with strike-location notes and head/tension metadata | TBD | measurement_required | Define slap-tone target metrics separately from bass cavity response | validation.csv | measurement_required
VL-005 | CAD/djembe-body/parametric-goblet.csv | L1_packet | parametric goblet geometry from analysis profile | Selected S/M/L shell geometry tied to measured or reviewed dimensions | head neck foot height and profile basis recorded | Caliper/tape measurements or reviewed CAD/design-table export | TBD | measurement_required | Promote one selected shell profile into reviewed geometry authority before cut lists | design.md; CAD/djembe-body/parametric-goblet.csv | measurement_required
VL-006 | head and tensioning setup | L1_packet | README build-history notes and current BOM placeholders | Head material diameter collar fit rope ring and tuning state logged | all setup fields completed before acoustic comparison | Photo documentation plus measured head/hardware/tuning notes | TBD | measurement_required | Capture head/tension metadata in the same session as strike measurements | bom.csv; photo-shotlist.md | source_needed
VL-007 | construction path decision | L1_packet | README construction-path alternatives | Segmented stack curved stave or lathe-finish path selected for next build | one path selected with path-specific risk notes | Decision record plus sketch reviewed CAD or design-table plan | TBD | measurement_required | Choose one construction path before any shop-facing cut list or jig plan | design.md | measurement_required
VL-008 | visual-output-register.csv | L1_packet | visual authority guard from instrument-maker | Photos scans figures and previews recorded as non-authority | register validates with zero errors | Run validate_visual_authority.py on visual-output-register.csv | TBD | measurement_required | Keep images and previews out of fabrication authority until reviewed CAD/DXF/design-table evidence exists | visual-output-register.csv | n_a

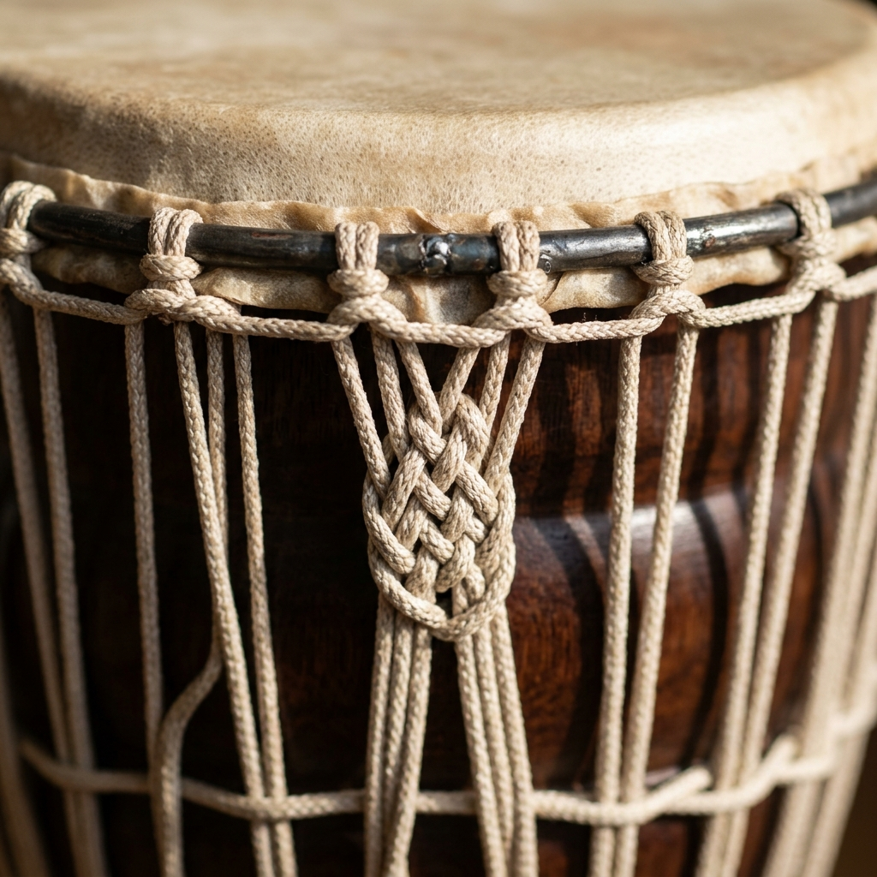
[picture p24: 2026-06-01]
images/macro/rope-tuning-weave.png

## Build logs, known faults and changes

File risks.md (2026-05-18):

# Djembe Starter Packet Risks

Current status: bare-bones readiness packet.
Fabrication authority: not build-ready.

## Scope Risks

| Risk | Why it matters | Mitigation |
| --- | --- | --- |
| Analysis is mistaken for empirical proof | The FEM work is useful, but no mic/FFT strike measurements are recorded. | Keep acoustic claims at analysis-only until `validation.csv` strike gates are filled. |
| Historical builds imply current reproducibility | Photos and Morgan Drums history show experience, not a current shop process. | Require current dimensions, process notes, and safety checks before build-ready claims. |
| Segmented, curved-stave, and lathe-finish paths get mixed | Each path has different cut geometry and failure modes. | Choose one construction path before writing cut lists or fixture drawings. |

## Acoustic Risks

| Risk | Why it matters | Mitigation |
| --- | --- | --- |
| Bass cavity model omits membrane coupling | Real djembe sound includes head modes and player strike technique. | Measure bass, open tone, and slap separately with repeatable strike notes. |
| Head tension dominates measured tone | The same shell can sound different under different rope tension and head condition. | Record head material, diameter, tuning state, and tension method with every acoustic test. |
| Room and mic placement skew FFT results | Low-frequency drum measurements are sensitive to placement and room modes. | Standardize mic distance, room notes, strike count, and analysis window. |

## Fabrication Risks

| Risk | Why it matters | Mitigation |
| --- | --- | --- |
| Stave joints open during turning or tuning | Curved shells and rope tension put stress on glue joints. | Validate glue-up on coupons or scrap rings before full-shell work. |
| Jig geometry is under-specified | A router or variable-angle sled can create unsafe or non-repeatable cuts. | Promote reviewed drawings/CAD and run scrap trials before instrument stock. |
| Legacy CAD is over-trusted | SolidWorks archive files may not match current design intent or shop constraints. | Treat legacy CAD as reference until reviewed, exported, and tied to a decision record. |

## Safety Risks

| Risk | Why it matters | Mitigation |
| --- | --- | --- |
| Rope and ring tension failure | Rope-tuned drums store energy and can fail during tuning. | Specify hardware, inspect knots/rings, and test gradually with eye protection. |
| Lathe or router operations on irregular blanks | Goblet shells and curved staves can be difficult to fixture safely. | Add workholding plans, guards, and scrap tests before live cuts. |
| Dust and finish exposure | Drum shell woods and finishing materials can create respiratory or skin hazards. | Add PPE, ventilation, and SDS checks when materials are selected. |

## Evidence Risks

| Risk | Why it matters | Mitigation |
| --- | --- | --- |
| Photos become dimensional authority | Images are useful but can distort scale. | Use scale references and separate photos from measured tables. |
| Supplier rows look current | Starter BOM entries may be mistaken for purchase-ready recommendations. | Keep `source_status` explicit and re-check suppliers at purchase time. |
| Cultural context is too thin | The djembe has Mande origins and should not be framed as an invented object. | Keep lineage notes visible in README and public-facing packet text. |

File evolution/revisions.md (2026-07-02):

# Revision Register — djembe

| Rev | Date | Parent | Delta | Downstream artifacts invalidated |
| --- | --- | --- | --- | --- |
| A | 2026-07-01 | — | Stage 0 intake of current masters (`CAD/djembe.scad` + `CAD/djembe-body/parametric-goblet.csv` + `wolfram/djembe-goblet-acoustics.wl`). | none (no alpha/beta/production artifacts exist yet) |

Stage 0 only. Gate A has not been run; no Alpha compiles, vendor quotes, or production lock exist for this product.

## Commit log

2026-04-26 drum segmented
    [Large Ashiko - Pattern 1.xlsx, Large Ashiko - Pattern 2.xlsx, Large Ashiko - Pattern 3.xlsx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]
2026-04-27 Document recovered segmented djembe CAD archive
2026-04-27 conga segmented
    [Segmented Conga.csv]
2026-04-27 move to proper repo
    [Segmented Conga.csv]
2026-05-09 analysis: Helmholtz cavity FEM on the goblet body (Closes #1) (#2)
    L3-frontier acoustic-cavity validation of the lumped Helmholtz bass-tone
    prediction against a 1D Webster's-horn FEM on the parametric goblet
    profile.
    - analysis/helmholtz-fem/closed-form.md — A, L_eff, V_0 mapping for the
    goblet; lumped-baseline derivation citing skills/helmholtz-cavity-resonator.md.
    - analysis/helmholtz-fem/profile.py — parametric r(z) for Morgan-9/-10/-12
    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
    [parametric-goblet.csv, results.csv]
2026-05-18 Add djembe bare-bones starter packet (#5)
    [bom.csv, validation.csv]
2026-05-18 feat(learn-to-play): add djembe starter songbook (#3)
    * feat(learn-to-play): add djembe starter songbook (R4 claude-dan)
    Drop learn-to-play/ with 00-INDEX.md, scales/, fingerings/, and
    5 tunes (ABC + LilyPond + songsheet + notes). All tunes are
    public-domain traditional arrangements or original Heifer Zephyr
    compositions (MIT). Notation is at concert pitch; no external
    rendering tools required to read the ABC files.
    * fix: strip trailing whitespace from learn-to-play songsheets
    ---------
2026-05-18 Add djembe V5 validation loop (#6)
    [validation-loop.csv, validation.csv, visual-output-register.csv]
2026-05-23 Recover from 2026-05-18 hygiene-bot stash; restore 10 Djembe SolidWorks parts/assemblies + diagram PNG
    [5degree 18 part 36 face.SLDPRT, Djembe C - 3 flat face.SLDASM, Djimbey A.SLDPRT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]
2026-05-31 Add image-gen concept prompt; wire explorer images
2026-06-23 feat(wolfram): deploy interactive model + live explorer embed (#11)
    * Add Wolfram acoustics model + wire engineering.wolfram into capstone-manifest
    wolfram/djembe-goblet-acoustics.wl — Manipulate over Morgan S/M/L goblet profiles:
    lumped Helmholtz f₀ slider (head dia, neck dia, eff. length, bowl volume). Pulls
    profile data from parametric-goblet.csv; CloudDeploy-ready, embed URL pending.
    capstone-manifest.json — adds engineering.wolfram[] block (cloud_url: pending)
    so wolfram_emit_engineering_manifest can wire the CloudDeploy URL once published.
    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
    [cut-list.csv, sourcing.csv]
2026-07-02 V5 packet refresh: status line, provenance, parametric OpenSCAD master, evolution intake
    Baseline validate_v5_packet.py: 2 failures before (no README Status line;
    missing cad/mcp-session-log.md) -> 0 failures / 1 expected pending_measurement
    WARN after.
    - README: added `**Status:** L2 V5 build-packet candidate` line, renamed
    "Bare-bones packet" to "Readiness" + "Packet Contents" sections (caveat
    prose preserved), added CAD/Wolfram/evolution bullets, and updated the
    CAD status table row for the new goblet-body master.
    - Authored CAD/djembe.scad: parametric goblet-body envelope master (S/M/L
    Morgan profiles sourced verbatim from CAD/djembe-body/parametric-goblet.csv
    — head/neck/fo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
    [djembe.scad, visual-output-register.csv]
2026-07-02 feat(arena): Code-CAD Arena Round 2 winning model (generated, not a master)
    Blind-vote winner from makerbench-hwe round2 (all-assembly round, 3D-viewer
    voting). See arena/round2/provenance.json.
    Claude-Session: https://claude.ai/code/session_01Ew72pzuM36NwvCSbcruyxs
    [stave-djembe-arena-winner.scad, stave-djembe-arena-winner.stl]
2026-07-03 chore: add .gitattributes for CRLF normalization + binary handling (#14)
    Adds the standard maker/CAD .gitattributes template (text=auto eol=lf,
    explicit LF for code/docs/config, binary excludes for CAD/image/office
    formats) so this repo stops being exposed to CRLF drift when edited by
    both Windows tools and WSL.
    Does NOT renormalize existing tracked blobs (git add --renormalize) —
    that is a deliberate, separately-reviewed follow-up per the tracking
    issue, to avoid a surprise mass line-ending diff in this PR.
    Refs tonykoop/instrument-maker#215
